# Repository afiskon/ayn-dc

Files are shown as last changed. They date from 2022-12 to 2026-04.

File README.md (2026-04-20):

# AYN/DC

QRP CW Transceiver

* Covers 40, 30, 20 and 17 meters
* Easily modifiable for other 4 bands
* DC receiver with sideband suppression
* Simple but effective AGC
* Supports RIT and XIT
* 10-30 WPM Elekey-B type keyer + straight key mode
* Keyer settings are saved in EEPROM
* ~5W class C power amplifier
* Has a VCC indicator and a SWR meter
* PCB is designed to fit into Hammond 1590BB enclosure
* The project is 100% open-source

Links:

* Article (in Russian): https://eax.me/2023/2023-01-16-ayn-dc-transceiver.html
* Demo: https://www.youtube.com/watch?v=9x_RN68QJhk

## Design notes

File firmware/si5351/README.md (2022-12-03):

# stm32-si5351

HAL-based Si5351 driver for STM32.

Main respository: https://github.com/afiskon/stm32-si5351

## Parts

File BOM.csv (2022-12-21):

Reference | Quantity | Value | Footprint
C13 C18 C21 C58 C59 | 5 | 0.01u | Capacitor_SMD:C_0805_2012Metric_Pad1.15x1.40mm_HandSolder
C2 | 1 | 470u | Connector_PinSocket_2.54mm:PinSocket_1x02_P2.54mm_Vertical
C23 C31 C46 | 3 | 0.047u | Capacitor_SMD:C_0805_2012Metric_Pad1.15x1.40mm_HandSolder
C26 C27 C36 | 3 | 1000p | Capacitor_SMD:C_0805_2012Metric_Pad1.15x1.40mm_HandSolder
C29 C66 C69 | 3 | 100p | Capacitor_SMD:C_0805_2012Metric_Pad1.15x1.40mm_HandSolder
C3 C6 C24 | 3 | 0.47u | Capacitor_SMD:C_0805_2012Metric_Pad1.15x1.40mm_HandSolder
C32 C40 | 2 | 0.033u | Capacitor_SMD:C_0805_2012Metric_Pad1.15x1.40mm_HandSolder
C33 C38 C39 | 3 | 2200p | Capacitor_SMD:C_0805_2012Metric_Pad1.15x1.40mm_HandSolder
C34 | 1 | 4.7u | Capacitor_SMD:CP_Elec_4x5.4
C35 C47 | 2 | 10u | Capacitor_SMD:CP_Elec_4x5.4
C1 C4 C5 C7 C8 C9 C10 C11 C12 C14 C15 C16 C17 C19 C20 C22 C25 C28 C30 C37 C42 C43 C44 C49 C50 C51 C53 C54 C55 C56 C57 | 31 | 0.1u | Capacitor_SMD:C_0805_2012Metric_Pad1.15x1.40mm_HandSolder
C41 | 1 | 6800p | Capacitor_SMD:C_0805_2012Metric_Pad1.15x1.40mm_HandSolder
C48 | 1 | 1u | Capacitor_SMD:CP_Elec_4x5.4
C52 | 1 | 220u | Capacitor_SMD:CP_Elec_8x10.5
C60 | 1 | 1-20p | My_Library:C_Trim_THD_L7.0mm_W6.5mm_P5.00mm
C61 C64 | 2 | 150p | Capacitor_SMD:C_0805_2012Metric_Pad1.15x1.40mm_HandSolder
C62 C63 C67 C68 C72 C73 C77 C78 | 8 | 1-30p | My_Library:C_Trim_THD_L7.0mm_W6.5mm_P5.00mm
C65 C70 C75 | 3 | 1-10p | My_Library:C_Trim_THD_L7.0mm_W6.5mm_P5.00mm
C71 C74 | 2 | 47p | Capacitor_SMD:C_0805_2012Metric_Pad1.15x1.40mm_HandSolder
C76 C79 | 2 | 68p | Capacitor_SMD:C_0805_2012Metric_Pad1.15x1.40mm_HandSolder
D1 D2 D3 D6 D7 D8 D9 D10 D11 D12 D13 | 11 | 1N4148W | Diode_SMD:D_SOD-123
D14 | 1 | SS14 | Diode_SMD:D_SMA_Handsoldering
D4 D5 | 2 | 1N34 / D311 / etc | Diode_THT:D_DO-41_SOD81_P3.81mm_Vertical_AnodeUp
J2 | 1 | Si5351 Module | Connector_PinSocket_2.54mm:PinSocket_1x07_P2.54mm_Vertical
J3, J4 | 1 | Blue Pill
K1 K2 K3 K4 K5 K6 K7 K8 K9 | 9 | G6K-2F-Y or HFD4/12-S | Relay_SMD:Relay_DPDT_Omron_G6K-2F-Y
L1 L2 | 2 | 1000u | Inductor_THT:L_Axial_L6.6mm_D2.7mm_P10.16mm_Horizontal_Vishay_IM-2
Q1 Q5 Q7 Q8 Q9 Q10 Q11 | 7 | MMBT3904 | Package_TO_SOT_SMD:SOT-23
Q2 Q3 | 2 | MMBF170 | Package_TO_SOT_SMD:SOT-23
Q4 | 1 | MMBT3906 | Package_TO_SOT_SMD:SOT-23
Q6 | 1 | RD15HVF1 | Package_TO_SOT_THT:TO-220-3_Vertical
R1 R41 | 2 | 15K | Resistor_SMD:R_0805_2012Metric_Pad1.15x1.40mm_HandSolder
R7 R8 R10 R13 | 4 | 300 | Resistor_SMD:R_0805_2012Metric_Pad1.15x1.40mm_HandSolder
R19 R40 | 2 | 8.2K | Resistor_SMD:R_0805_2012Metric_Pad1.15x1.40mm_HandSolder
R2 R15 R16 R54 R66 R67 R68 R69 | 8 | 4.7K | Resistor_SMD:R_0805_2012Metric_Pad1.15x1.40mm_HandSolder
R20 R28 R53 R59 R71 R72 | 6 | 1K | Resistor_SMD:R_0805_2012Metric_Pad1.15x1.40mm_HandSolder
R21 R22 R23 R24 R29 R30 R31 R32 R57 | 9 | 3.3K | Resistor_SMD:R_0805_2012Metric_Pad1.15x1.40mm_HandSolder
R26 | 1 | 5.1K | Resistor_SMD:R_0805_2012Metric_Pad1.15x1.40mm_HandSolder
R27 | 1 | 4.3K | Resistor_SMD:R_0805_2012Metric_Pad1.15x1.40mm_HandSolder
R3 | 1 | 2.7K | Resistor_SMD:R_0805_2012Metric_Pad1.15x1.40mm_HandSolder
R35 R36 | 2 | 33K | Resistor_SMD:R_0805_2012Metric_Pad1.15x1.40mm_HandSolder
R37 R38 | 2 | 47K | Resistor_SMD:R_0805_2012Metric_Pad1.15x1.40mm_HandSolder
R45 | 1 | 750K | Resistor_SMD:R_0805_2012Metric_Pad1.15x1.40mm_HandSolder
R46 R47 | 2 | 36K | Resistor_SMD:R_0805_2012Metric_Pad1.15x1.40mm_HandSolder
R50 | 1 | 10 | Resistor_SMD:R_0805_2012Metric_Pad1.15x1.40mm_HandSolder
R51 | 1 | 1Meg | Resistor_SMD:R_0805_2012Metric_Pad1.15x1.40mm_HandSolder
R52 | 1 | 470 | Resistor_SMD:R_0805_2012Metric_Pad1.15x1.40mm_HandSolder
R56 | 1 | 2.2K | Resistor_SMD:R_0805_2012Metric_Pad1.15x1.40mm_HandSolder
R58 | 1 | 1.3K | Resistor_SMD:R_0805_2012Metric_Pad1.15x1.40mm_HandSolder
R6 R17 R25 R33 R43 R49 R55 | 7 | 22 | Resistor_SMD:R_0805_2012Metric_Pad1.15x1.40mm_HandSolder
R60 | 1 | 68 | Resistor_SMD:R_0805_2012Metric_Pad1.15x1.40mm_HandSolder
R61 | 1 | 6 | Resistor_SMD:R_0805_2012Metric_Pad1.15x1.40mm_HandSolder
R62 R63 R64 R65 | 4 | 100 | Resistor_SMD:R_0805_2012Metric_Pad1.15x1.40mm_HandSolder
R70 | 1 | 100K | Resistor_SMD:R_0805_2012Metric_Pad1.15x1.40mm_HandSolder
R9 R11 R12 R14 R18 R34 R39 R42 R44 R48 | 10 | 10K | Resistor_SMD:R_0805_2012Metric_Pad1.15x1.40mm_HandSolder
RV1 RV2 | 2 | 50K | Potentiometer_THT:Potentiometer_Bourns_3296W_Vertical
RV3 | 1 | 500 | Potentiometer_THT:Potentiometer_Bourns_3296W_Vertical
RV4 RV5 | 2 | 10K | Potentiometer_THT:Potentiometer_Bourns_3296W_Vertical
T1 T2 T3 | 3 | FT37-43 | Package_DIP:DIP-4_W7.62mm
T4 T5 T6 T7 T8 T9 T10 T11 | 8 | T37-6 | Package_DIP:DIP-4_W7.62mm
U1 | 1 | L7805 | Package_TO_SOT_THT:TO-220-3_Vertical
U10 | 1 | LM386 | Package_SO:SO-8_5.3x6.2mm_P1.27mm
U11 | 1 | L7805 | Package_TO_SOT_SMD:TO-263-2
U2 | 1 | 24LC64 | Package_SO:SO-8_5.3x6.2mm_P1.27mm
U3 U6 U7 U8 U9 | 5 | NE5532 | Package_SO:SOIC-8_5.23x5.23mm_P1.27mm
U4 | 1 | FST3253 | Package_SO:TSSOP-16_4.4x5mm_P0.65mm
U5 | 1 | 74AC74 | Package_SO:SOIC-14_3.9x8.7mm_P1.27mm
J8 J9 J11 J12 | 1 | BN61-202
J6 | 2 | 220u | Through-hole capacitors, ideally 8 mm diameter

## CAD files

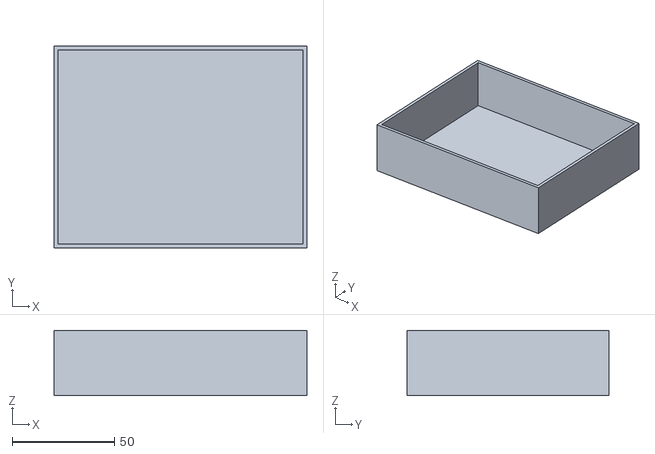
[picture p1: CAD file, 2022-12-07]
stl-files/dust-cover.stl
124.0 x 99.0 x 32.0

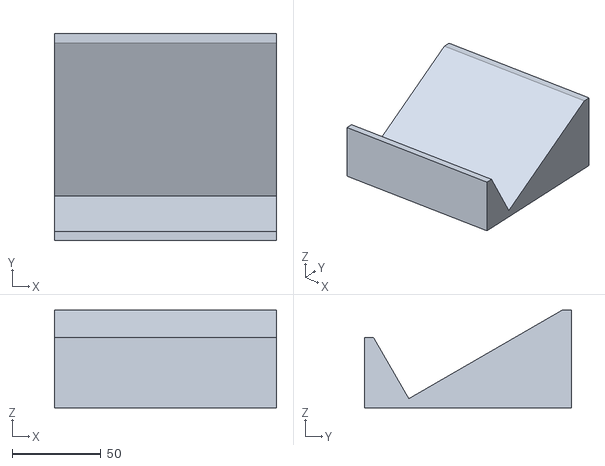
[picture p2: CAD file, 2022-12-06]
stl-files/desktop-stand.stl
125.0 x 116.6 x 55.0

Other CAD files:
stl-files/desktop-stand.scad
stl-files/dust-cover.scad

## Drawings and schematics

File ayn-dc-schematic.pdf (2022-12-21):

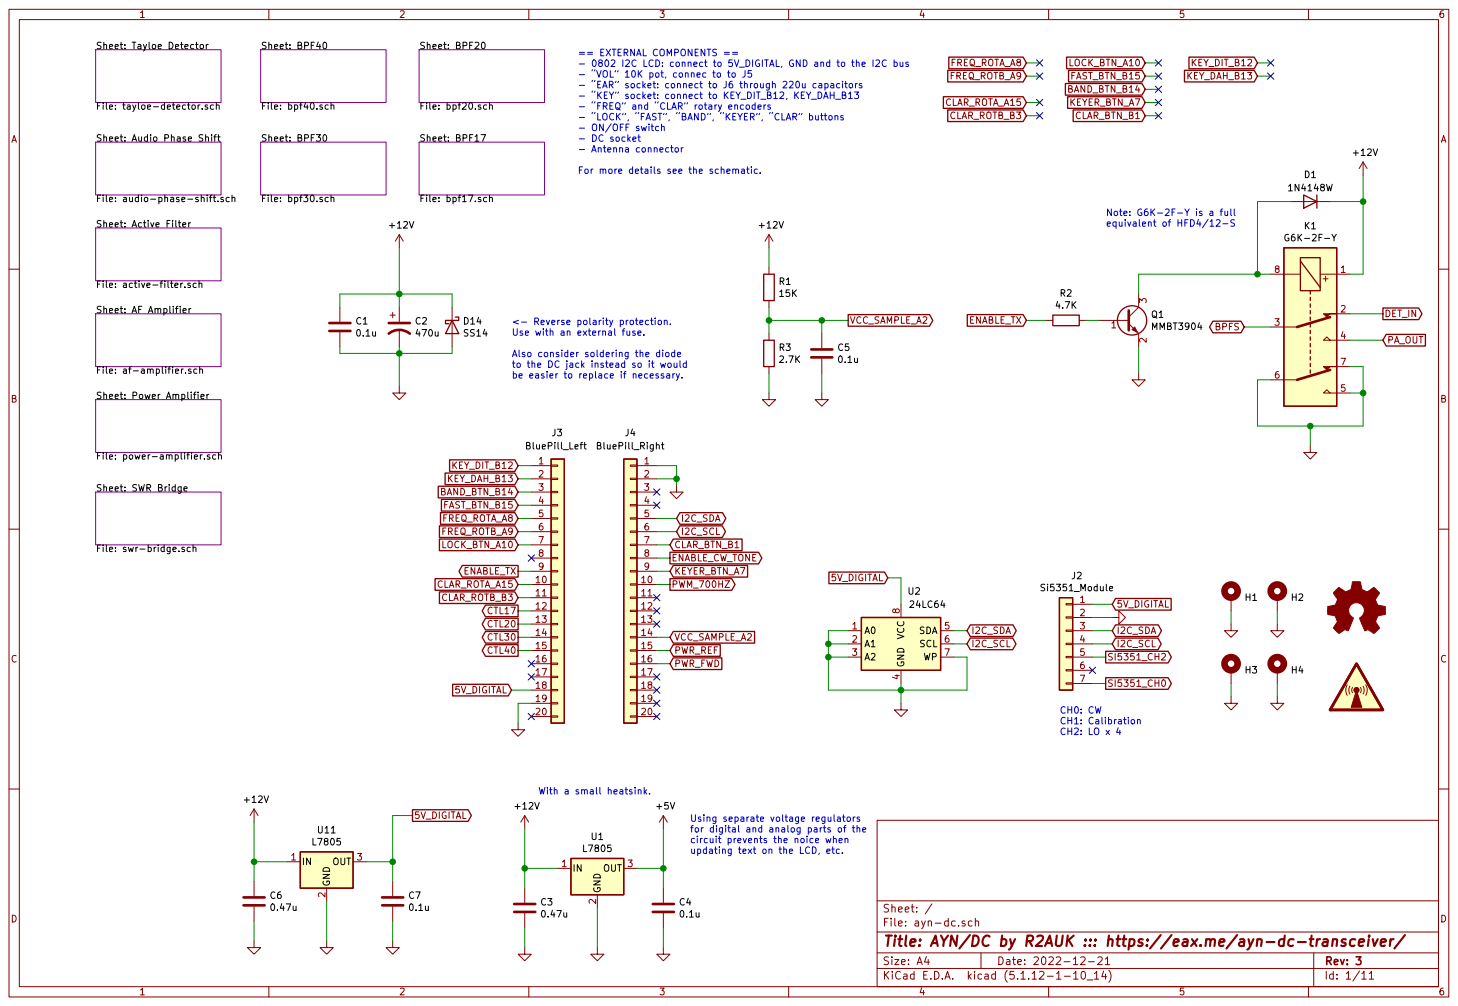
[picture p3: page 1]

== EXTERNAL COMPONENTS ==
- 0802 I2C LCD: connect to 5V_DIGITAL, GND and to the I2C bus
- VOL 10K pot, connec to to J5
- EAR socket: connect to J6 through 220u capacitors
- KEY socket: connect to KEY_DIT_B12, KEY_DAH_B13
- FREQ and CLAR rotary encoders
- LOCK, FAST, BAND, KEYER, CLAR buttons
- ON/OFF switch

File: tayloe-detector.sch Sheet: Audio Phase Shift File: audio-phase-shift.sch

<- Reverse polarity protection. Use with an external fuse. Also consider soldering the diode

to the DC jack instead so it would
be easier to replace if necessary.

File: power-amplifier.sch

File: swr-bridge.sch

4 SDA 5 SCL 6 WP 7 VCC

CH1: Calibration CH2: LO x 4 Using separate voltage regulators

for digital and analog parts of the
circuit prevents the noice when
updating text on the LCD, etc.

File: ayn-dc.sch Sheet: /
Id: 1/11 Title: AYN/DC by R2AUK ::: https://eax.me/ayn-dc-transceiver/

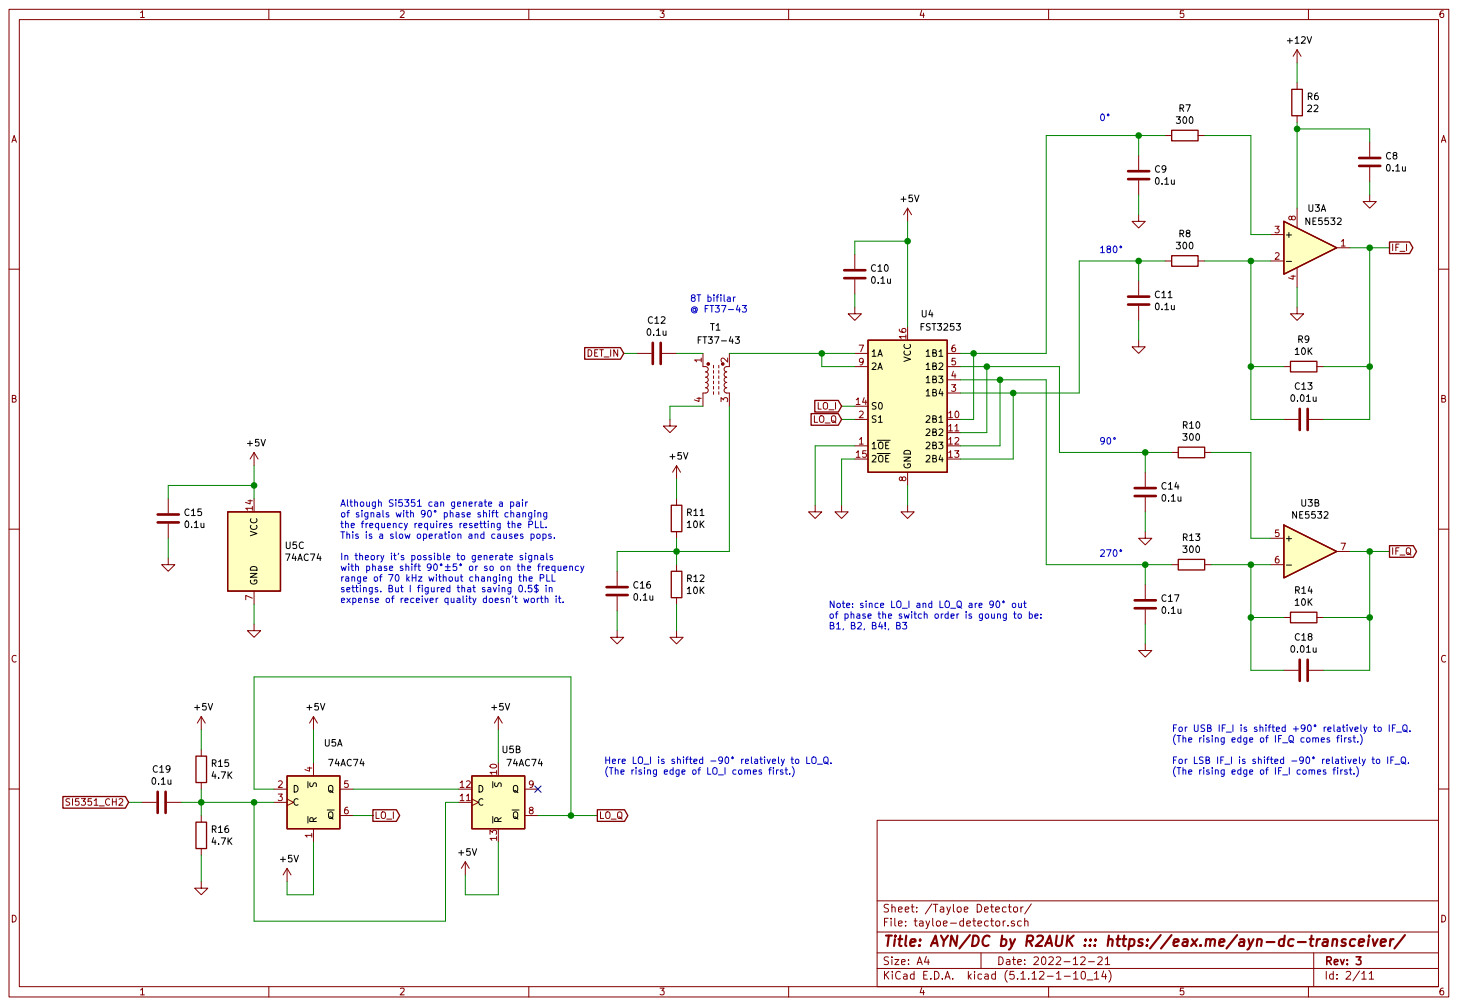
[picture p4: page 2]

0° 180° Note: since LO_I and LO_Q are 90° out of phase the switch order is goung to be: B1, B2, B4!, B3

Although Si5351 can generate a pair
of signals with 90° phase shift changing
the frequency requires resetting the PLL.
This is a slow operation and causes pops.

In theory its possible to generate signals
with phase shift 90°±5° or so on the frequency
range of 70 kHz without changing the PLL
settings. But I figured that saving 0.5$ in

For USB IF_I is shifted +90° relatively to IF_Q.
(The rising edge of IF_Q comes first.)

Here LO_I is shifted -90° relatively to LO_Q.
(The rising edge of LO_I comes first.)

For LSB IF_I is shifted -90° relatively to IF_Q.
(The rising edge of IF_I comes first.)

File: tayloe-detector.sch
Id: 2/11 Title: AYN/DC by R2AUK ::: https://eax.me/ayn-dc-transceiver/

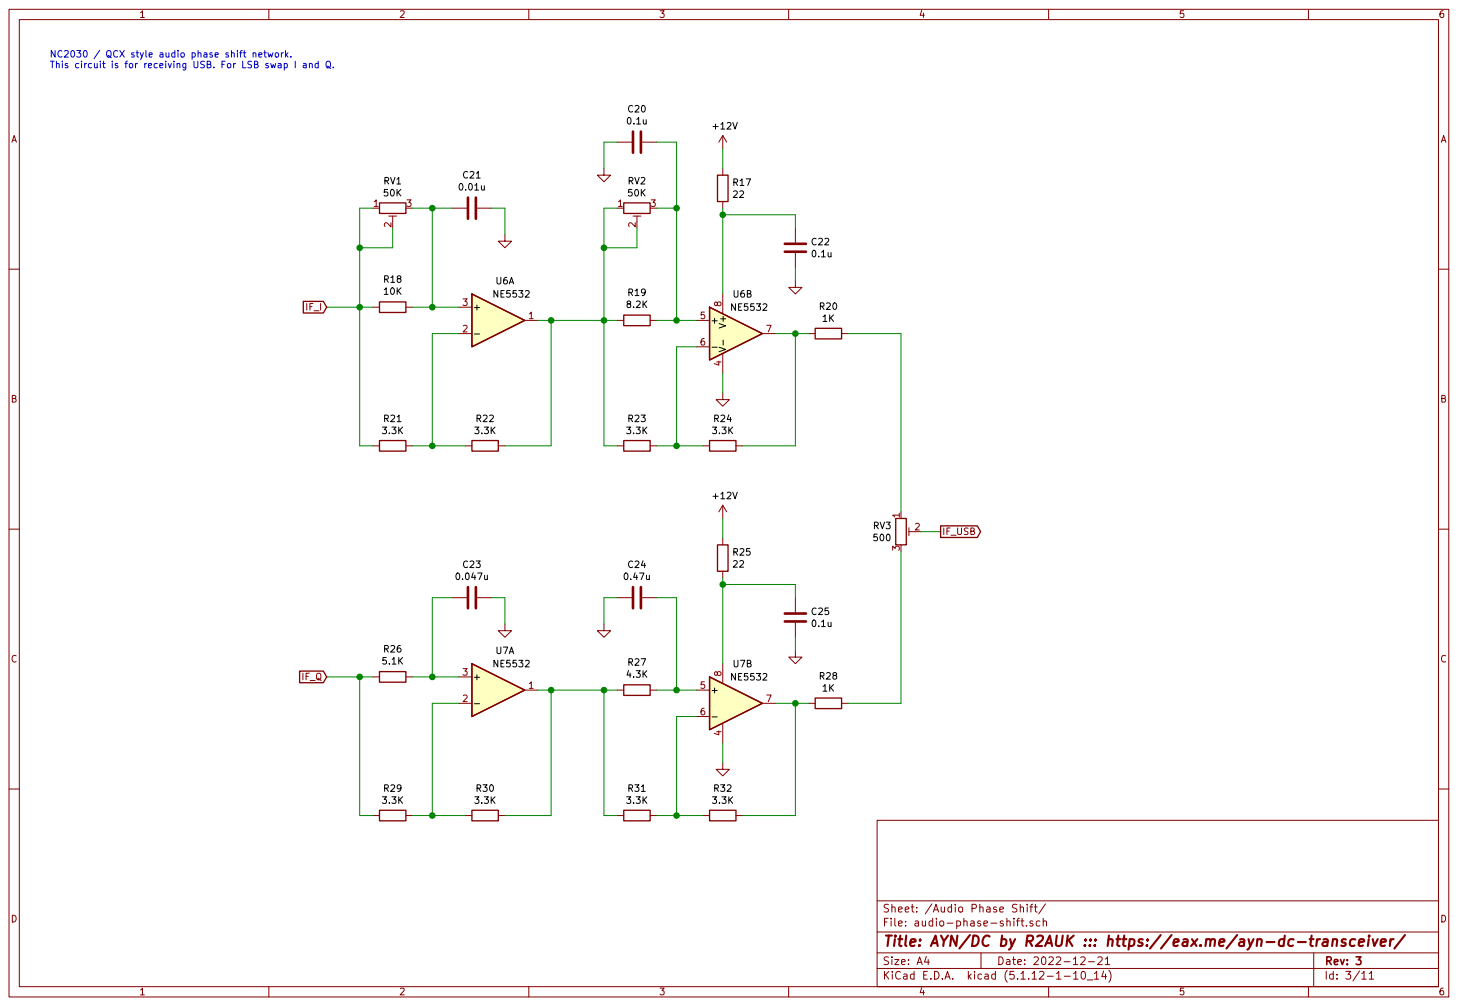
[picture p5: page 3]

NC2030 / QCX style audio phase shift network.
This circuit is for receiving USB. For LSB swap I and Q.

File: audio-phase-shift.sch Sheet: /Audio Phase Shift/
Id: 3/11 Title: AYN/DC by R2AUK ::: https://eax.me/ayn-dc-transceiver/

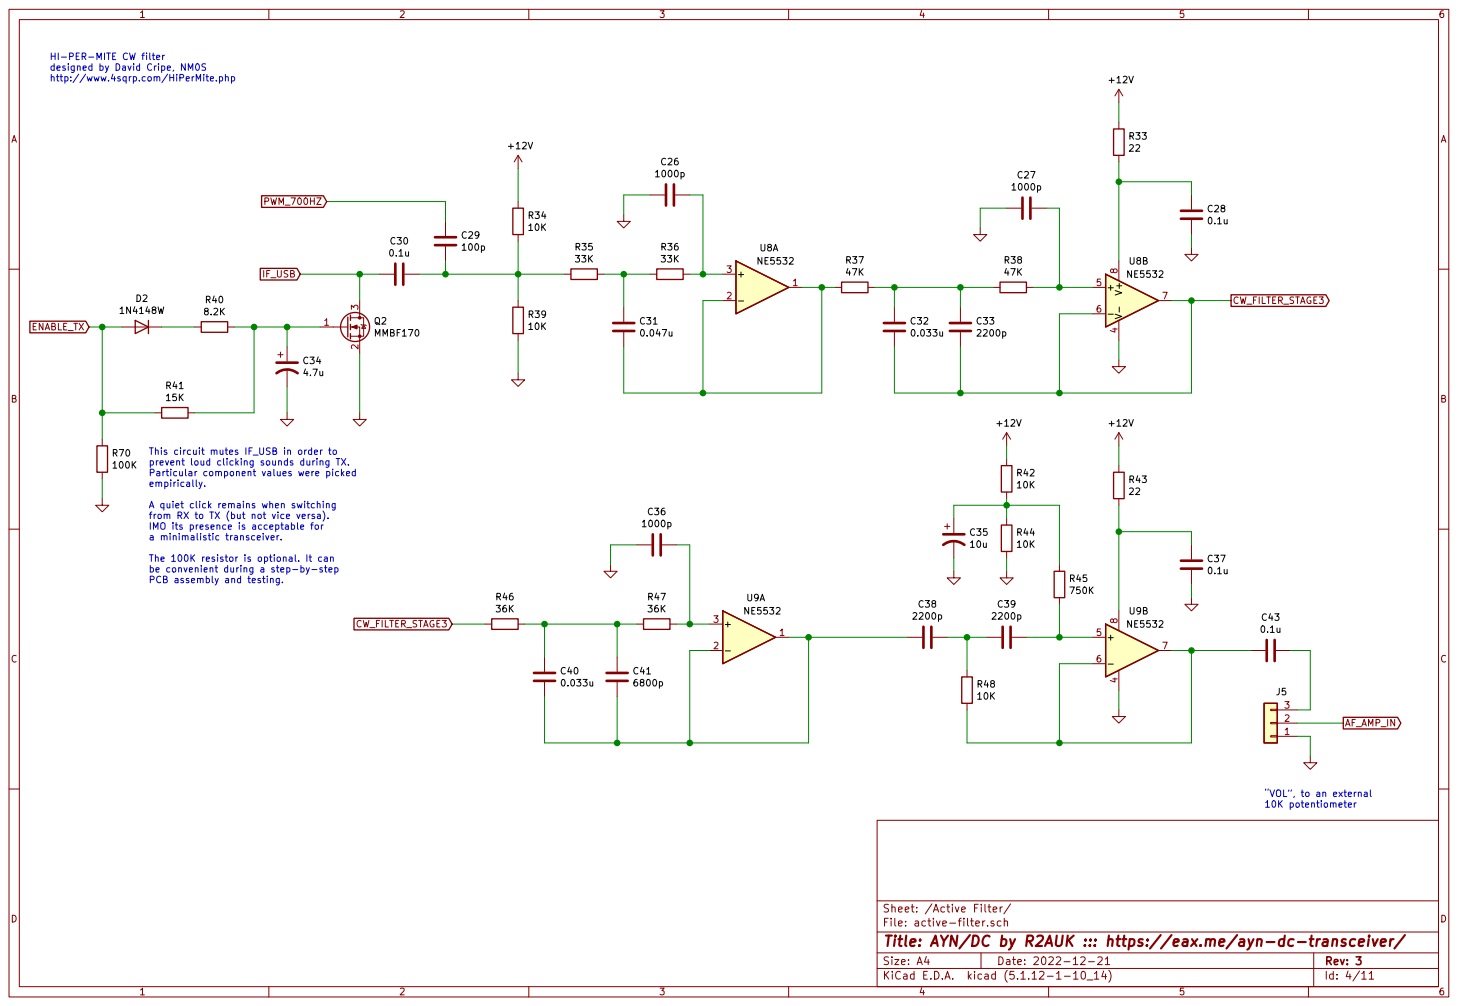
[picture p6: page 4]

HI-PER-MITE CW filter designed by David Cripe, NM0S

http://www.4sqrp.com/HiPerMite.php

This circuit mutes IF_USB in order to
prevent loud clicking sounds during TX.
Particular component values were picked
empirically.

A quiet click remains when switching
from RX to TX (but not vice versa).
IMO its presence is acceptable for a minimalistic transceiver. The 100K resistor is optional. It can

be convenient during a step-by-step
PCB assembly and testing.

VOL, to an external 10K potentiometer

Id: 4/11 Title: AYN/DC by R2AUK ::: https://eax.me/ayn-dc-transceiver/ File: active-filter.sch Sheet: /Active Filter/

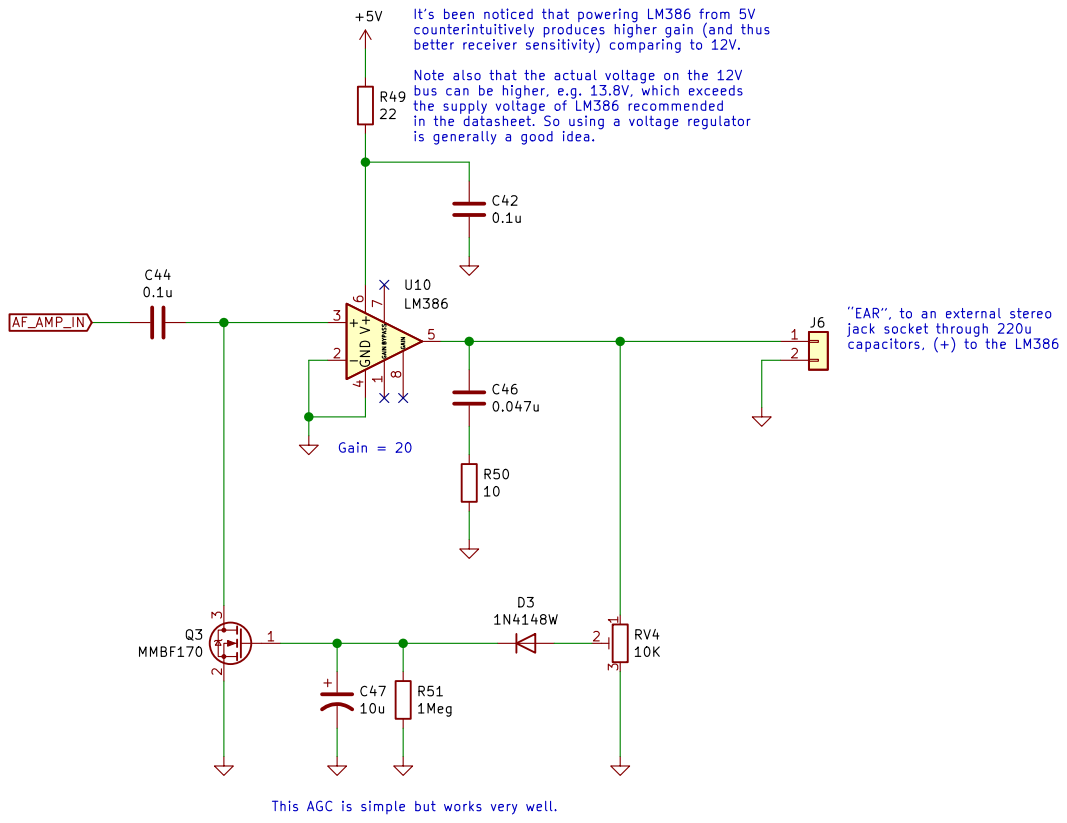
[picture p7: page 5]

is generally a good idea. Gain = 20 This AGC is simple but works very well.

Its been noticed that powering LM386 from 5V
counterintuitively produces higher gain (and thus
better receiver sensitivity) comparing to 12V.
the supply voltage of LM386 recommended
in the datasheet. So using a voltage regulator

Note also that the actual voltage on the 12V
bus can be higher, e.g. 13.8V, which exceeds

Sheet: /AF Amplifier/
File: af-amplifier.sch
Id: 5/11 Title: AYN/DC by R2AUK ::: https://eax.me/ayn-dc-transceiver/

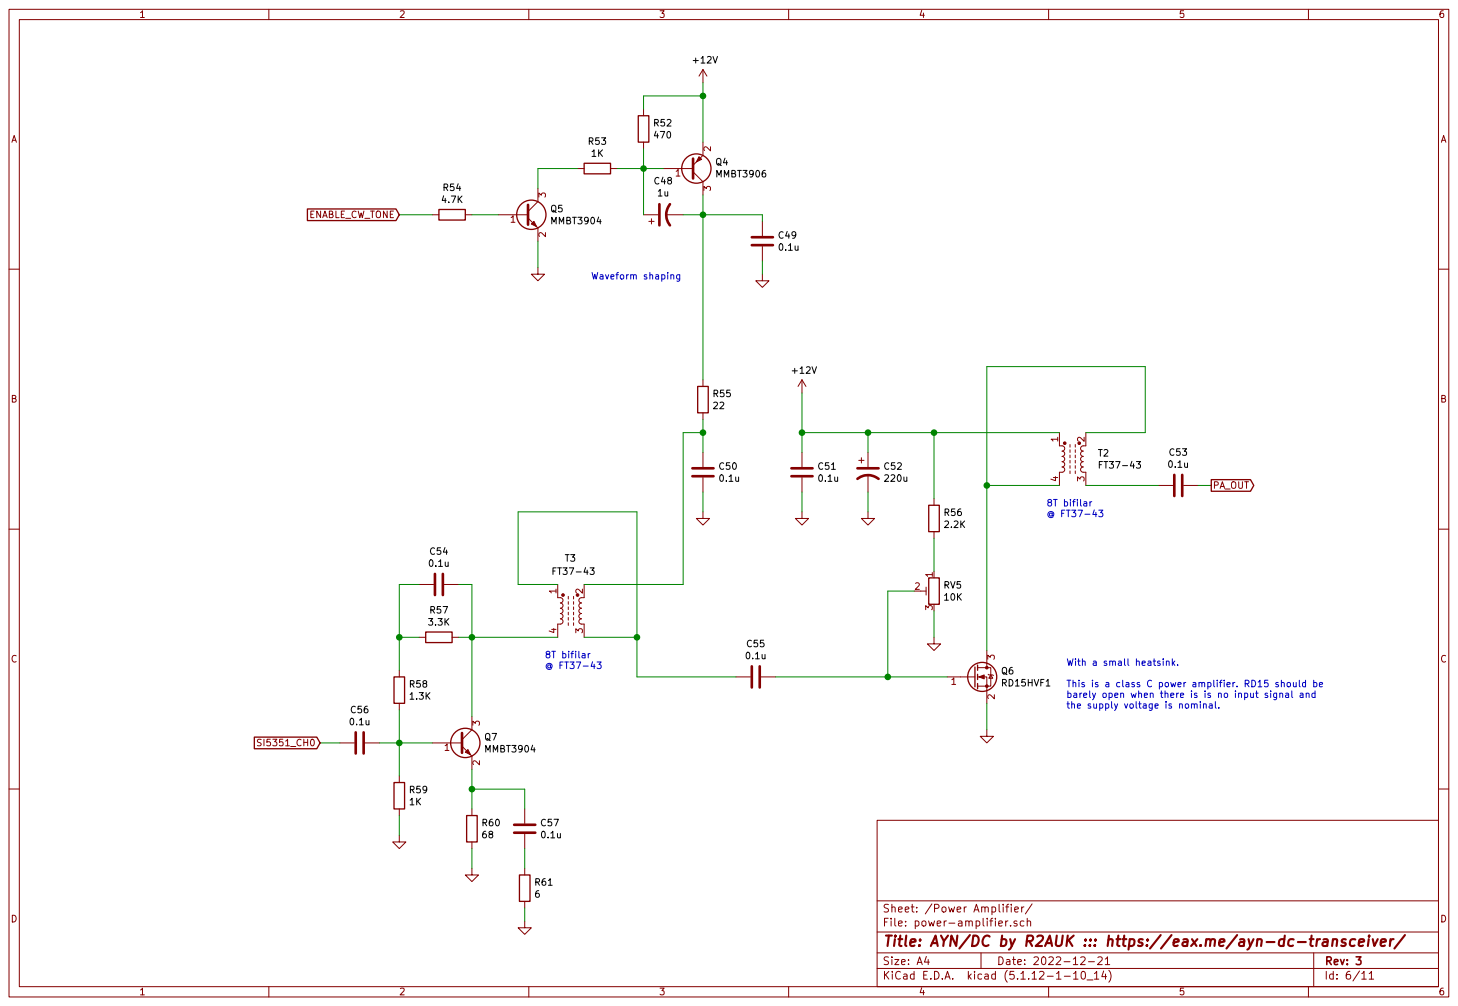
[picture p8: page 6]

PA_OUT With a small heatsink. This is a class C power amplifier. RD15 should be
the supply voltage is nominal. 8T bifilar @ FT37-43

barely open when there is is no input signal and

File: power-amplifier.sch
Id: 6/11 Title: AYN/DC by R2AUK ::: https://eax.me/ayn-dc-transceiver/

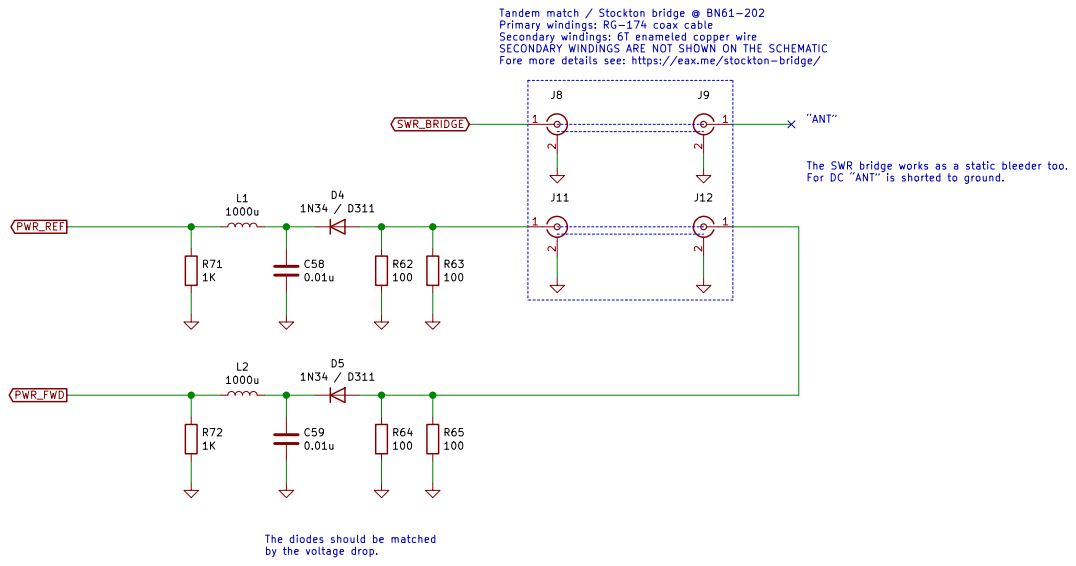
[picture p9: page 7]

Tandem match / Stockton bridge @ BN61-202
Primary windings: RG-174 coax cable
Secondary windings: 6T enameled copper wire SECONDARY WINDINGS ARE NOT SHOWN ON THE SCHEMATIC

Fore more details see: https://eax.me/stockton-bridge/ The diodes should be matched

The SWR bridge works as a static bleeder too.
For DC ANT is shorted to ground.

File: swr-bridge.sch
Id: 7/11 Title: AYN/DC by R2AUK ::: https://eax.me/ayn-dc-transceiver/

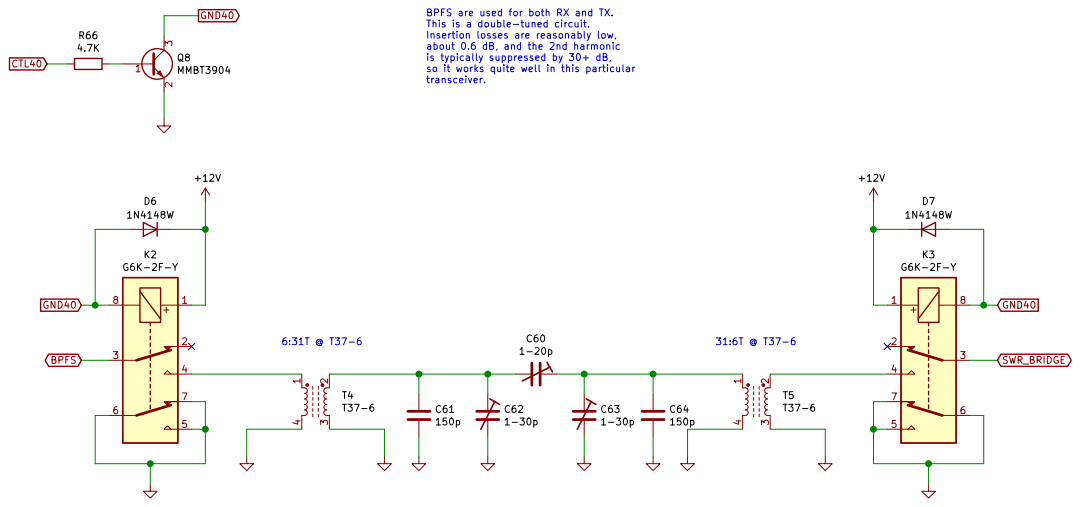
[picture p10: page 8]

Insertion losses are reasonably low, about 0.6 dB, and the 2nd harmonic

is typically suppressed by 30+ dB,
so it works quite well in this particular
transceiver.

Id: 8/11 Title: AYN/DC by R2AUK ::: https://eax.me/ayn-dc-transceiver/

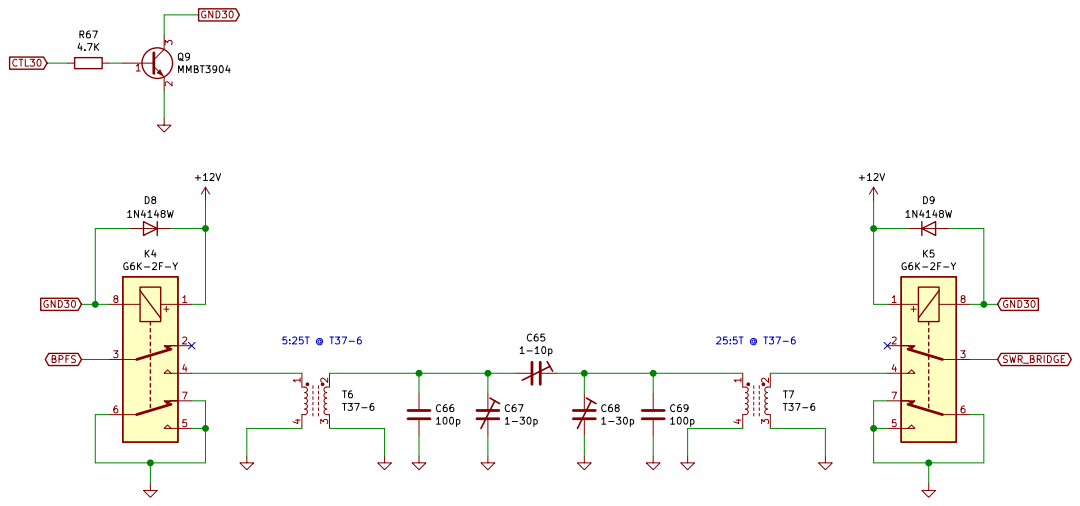
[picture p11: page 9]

File: bpf30.sch Sheet: /BPF30/
Id: 9/11 Title: AYN/DC by R2AUK ::: https://eax.me/ayn-dc-transceiver/

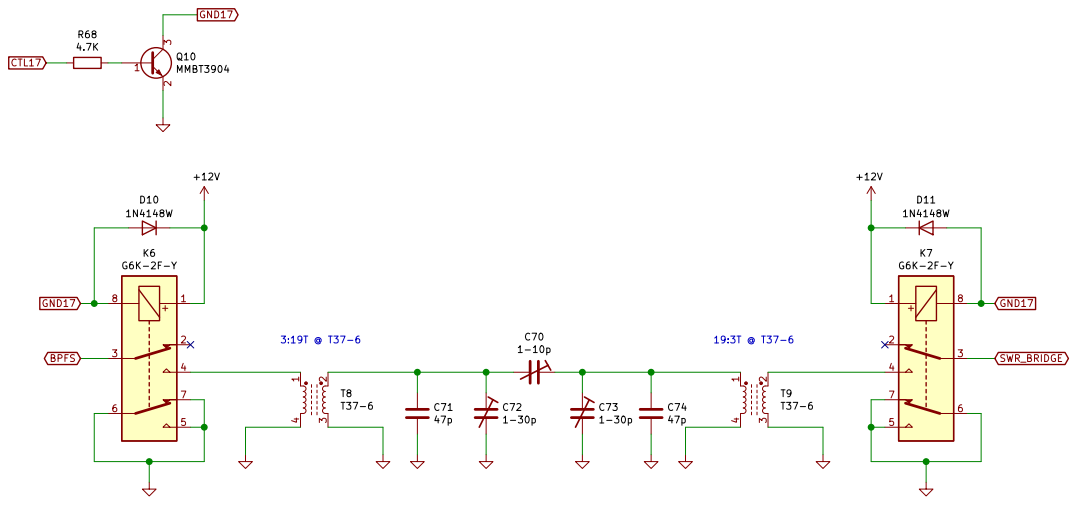
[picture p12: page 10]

File: bpf17.sch Sheet: /BPF17/
Id: 10/11 Title: AYN/DC by R2AUK ::: https://eax.me/ayn-dc-transceiver/

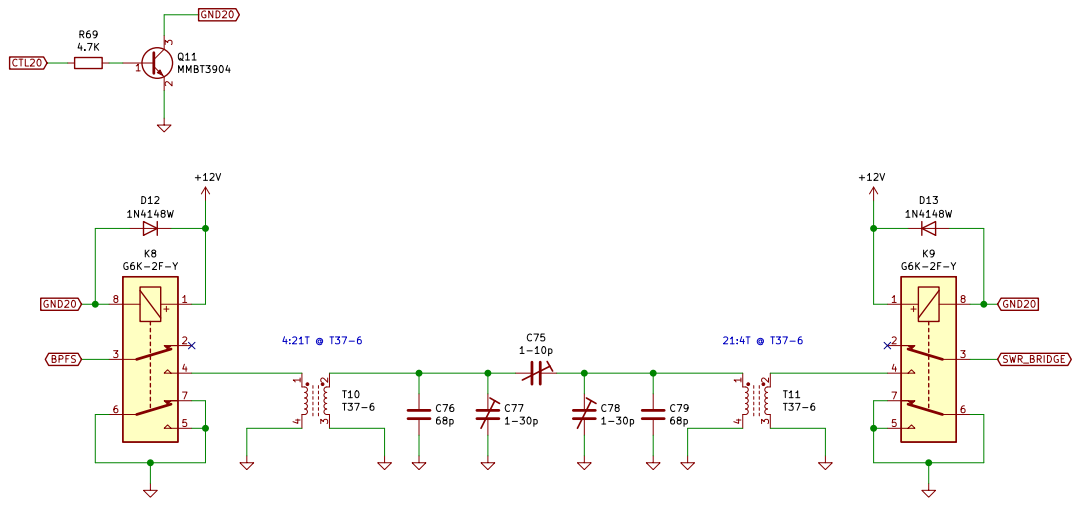
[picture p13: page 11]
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

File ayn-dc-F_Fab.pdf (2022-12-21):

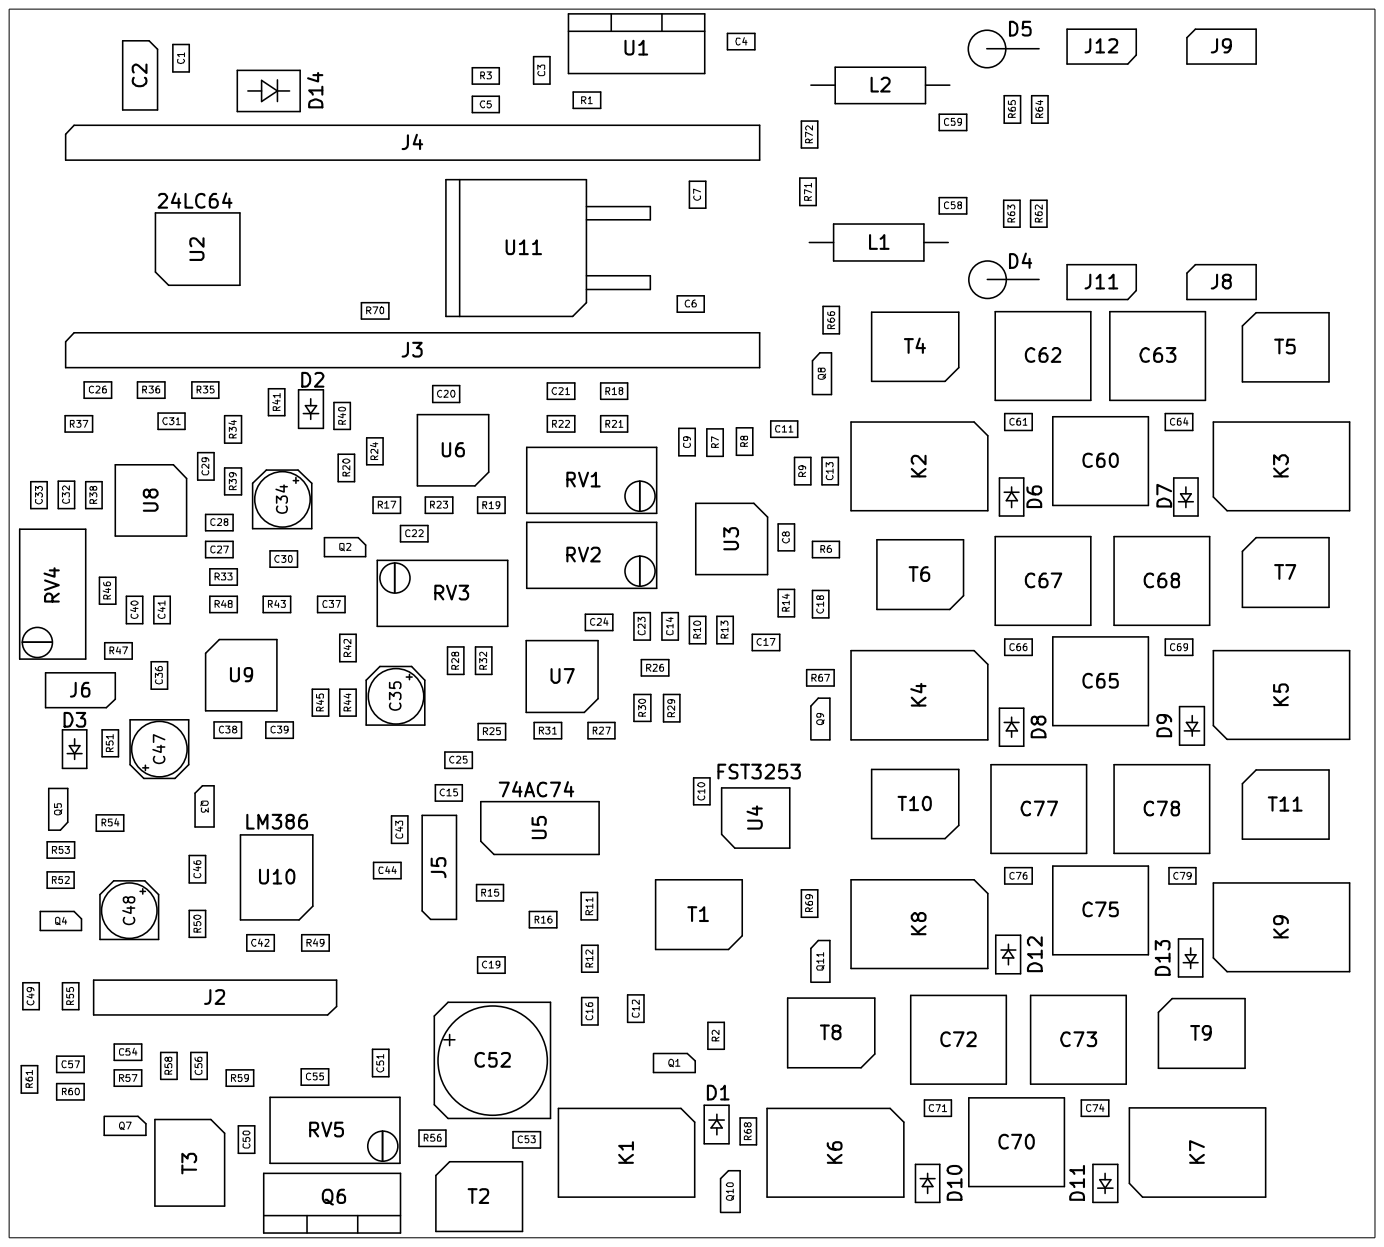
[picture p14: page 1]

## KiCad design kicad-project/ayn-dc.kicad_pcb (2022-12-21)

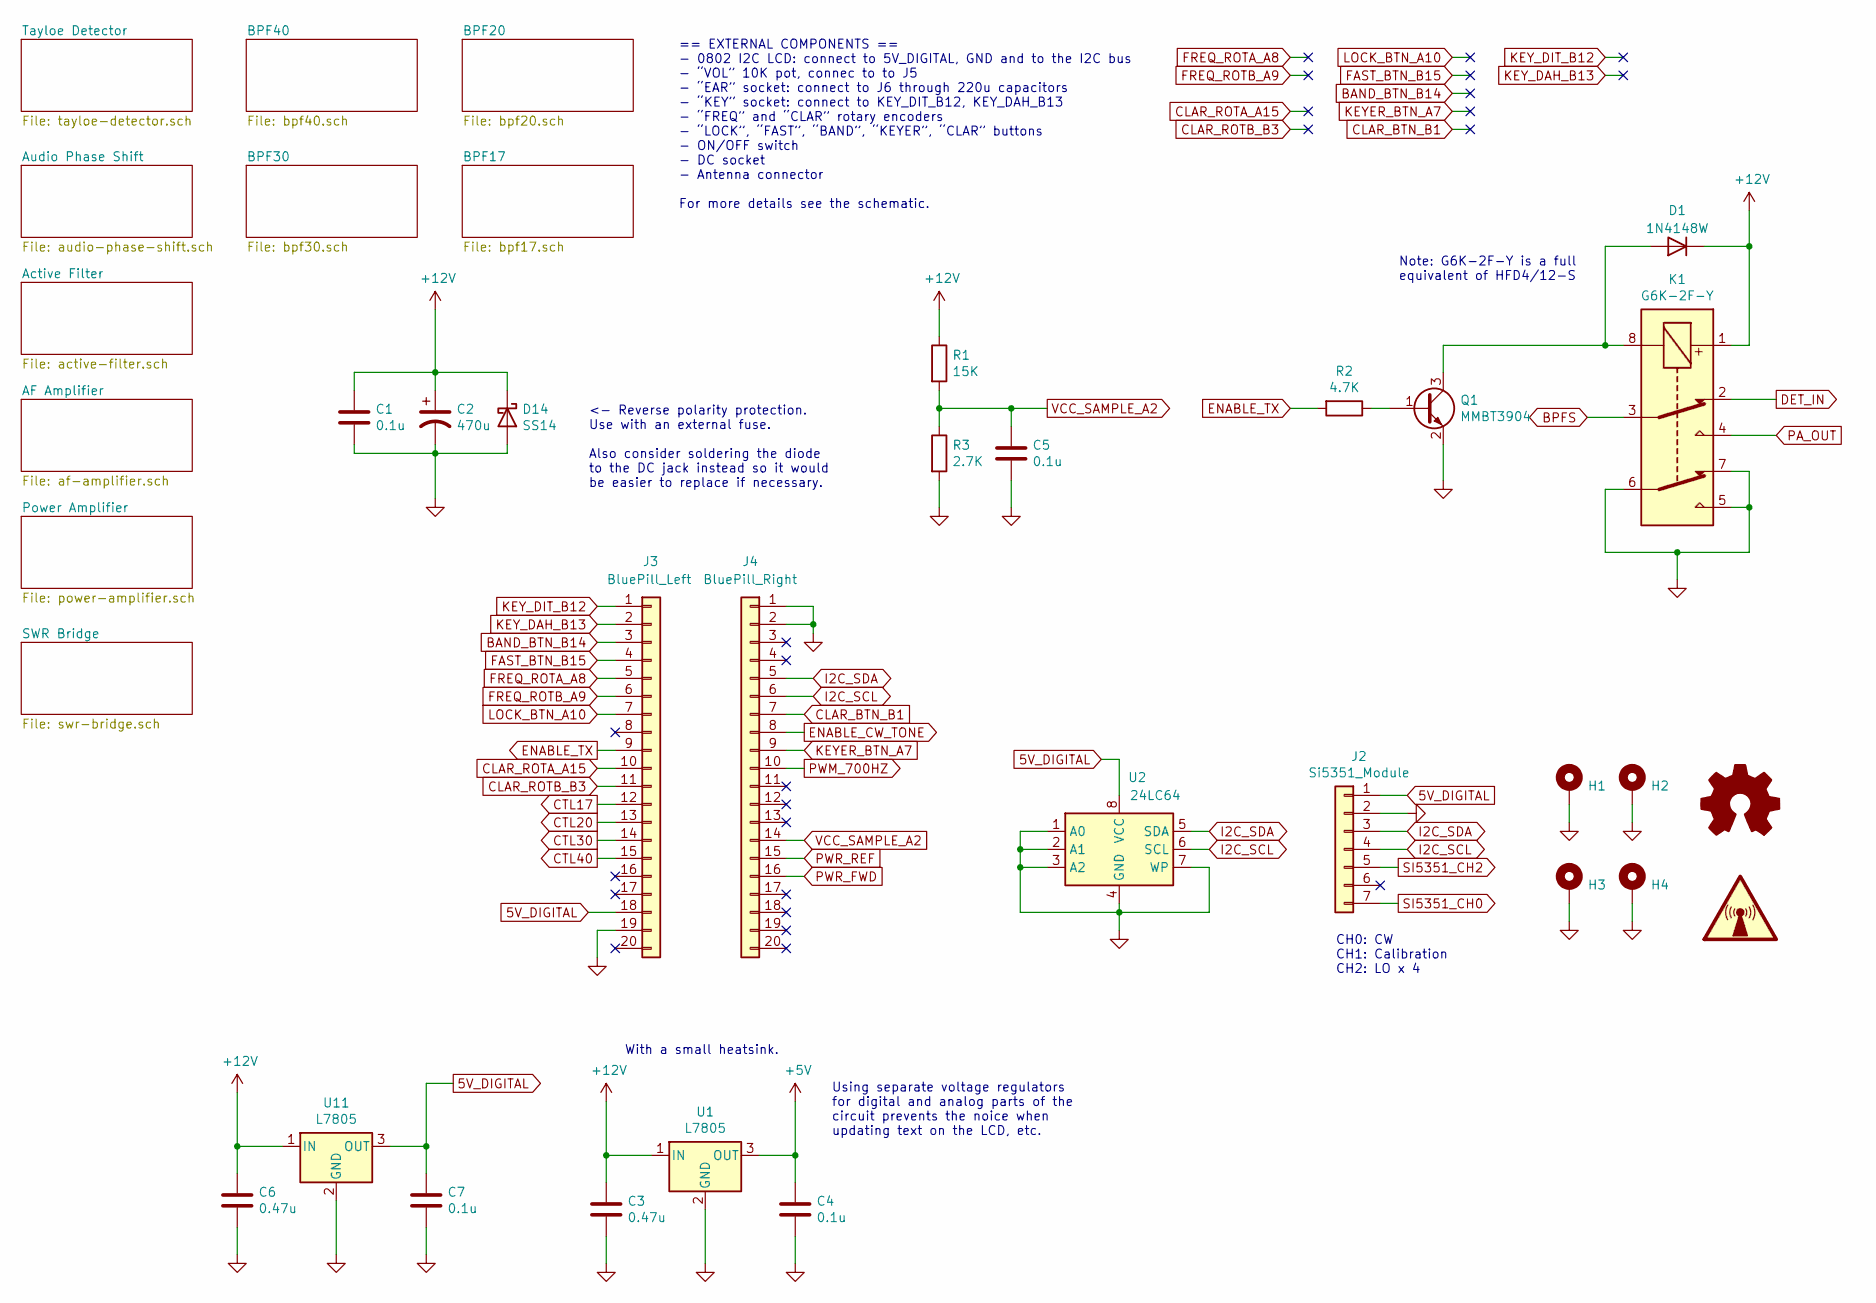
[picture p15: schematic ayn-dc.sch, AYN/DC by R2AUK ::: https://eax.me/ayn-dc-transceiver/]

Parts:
C1, C4, C5, C7: 0.1u; C_0805_2012Metric_Pad1.15x1.40mm_HandSolder
C2: 470u; PinSocket_1x02_P2.54mm_Vertical
C3, C6: 0.47u; C_0805_2012Metric_Pad1.15x1.40mm_HandSolder
D1: 1N4148W; D_SOD-123
D14: SS14; D_SMA_Handsoldering
H1, H2, H3, H4: MountingHole_Pad; MountingHole_3mm_Pad
J2: Si5351_Module; PinSocket_1x07_P2.54mm_Vertical
J3: BluePill_Left; PinSocket_1x20_P2.54mm_Vertical
J4: BluePill_Right; PinSocket_1x20_P2.54mm_Vertical
K1: G6K-2F-Y; Relay_DPDT_Omron_G6K-2F-Y
Q1: MMBT3904; SOT-23
R1: 15K; R_0805_2012Metric_Pad1.15x1.40mm_HandSolder
R2: 4.7K; R_0805_2012Metric_Pad1.15x1.40mm_HandSolder
R3: 2.7K; R_0805_2012Metric_Pad1.15x1.40mm_HandSolder
SYM1: Logo_Open_Hardware_Small; OSHW-Logo2_9.8x8mm_SilkScreen
SYM2: SYM_Radio_Waves_Large; KiCad-Logo_5mm_SilkScreen
U1: L7805; TO-220-3_Vertical
U2: 24LC64; SO-8_5.3x6.2mm_P1.27mm
U11: L7805; TO-263-2

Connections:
5V_DIGITAL: C7.1, J2.1, J3.18, U2.8 (VCC), U11.3 (OUT)
+5V: C4.1, U1.3 (OUT); also elsewhere on the board
+12V: C1.1, C2.1, C3.1, C6.1, D1.1 (K), D14.1 (K), K1.1, R1.1, U1.1 (IN), U11.1 (IN); also elsewhere on the board
BAND_BTN_B14: J3.3
BPFS: K1.3; also elsewhere on the board
CLAR_BTN_B1: J4.7
CLAR_ROTA_A15: J3.10
CLAR_ROTB_B3: J3.11
CTL17: J3.12; also elsewhere on the board
CTL20: J3.13; also elsewhere on the board
CTL30: J3.14; also elsewhere on the board
CTL40: J3.15; also elsewhere on the board
DET_IN: K1.2; also elsewhere on the board
ENABLE_CW_TONE: J4.8; also elsewhere on the board
ENABLE_TX: J3.9, R2.2; also elsewhere on the board
FAST_BTN_B15: J3.4
FREQ_ROTA_A8: J3.5
FREQ_ROTB_A9: J3.6
GND: C1.2, C2.2, C3.2, C4.2, C5.2, C6.2, C7.2, D14.2 (A), H1.1, H2.1, H3.1, H4.1, J2.2, J3.19, J4.1, J4.2, K1.5, K1.6, K1.7, Q1.2 (E), R3.2, U1.2 (GND), U2.1 (A0), U2.2 (A1), U2.3 (A2), U2.4 (GND), U2.7 (WP), U11.2 (GND); also elsewhere on the board
I2C_SCL: J2.4, J4.6, U2.6 (SCL)
I2C_SDA: J2.3, J4.5, U2.5 (SDA)
KEYER_BTN_A7: J4.9
KEY_DAH_B13: J3.2
KEY_DIT_B12: J3.1
LOCK_BTN_A10: J3.7
unnamed: D1.2 (A), K1.8, Q1.3 (C)
unnamed: Q1.1 (B), R2.1
PA_OUT: K1.4; also elsewhere on the board
PWM_700HZ: J4.10; also elsewhere on the board
PWR_FWD: J4.16; also elsewhere on the board
PWR_REF: J4.15; also elsewhere on the board
SI5351_CH0: J2.7; also elsewhere on the board
SI5351_CH2: J2.5; also elsewhere on the board
VCC_SAMPLE_A2: C5.1, J4.14, R1.2, R3.1

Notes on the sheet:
CH0: CW CH1: Calibration CH2: LO x 4
== EXTERNAL COMPONENTS == - 0802 I2C LCD: connect to 5V_DIGITAL, GND and to the I2C bus - “VOL” 10K pot, connec to to J5 - “EAR” socket: connect to J6 through 220u capacitors - “KEY” socket: connect to KEY_DIT_B12, KEY_DAH_B13 - “FREQ” and “CLAR” rotary encoders - “LOCK”, “FAST”, “BAND”, “KEYER”, “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
With a small heatsink.
Note: G6K-2F-Y is a full equivalent of HFD4/12-S
<- Reverse polarity protection. Use with an external fuse. Also consider soldering the diode to the DC jack instead so it would be easier to replace if necessary.
Using separate voltage regulators for digital and analog parts of the circuit prevents the noice when updating text on the LCD, etc.

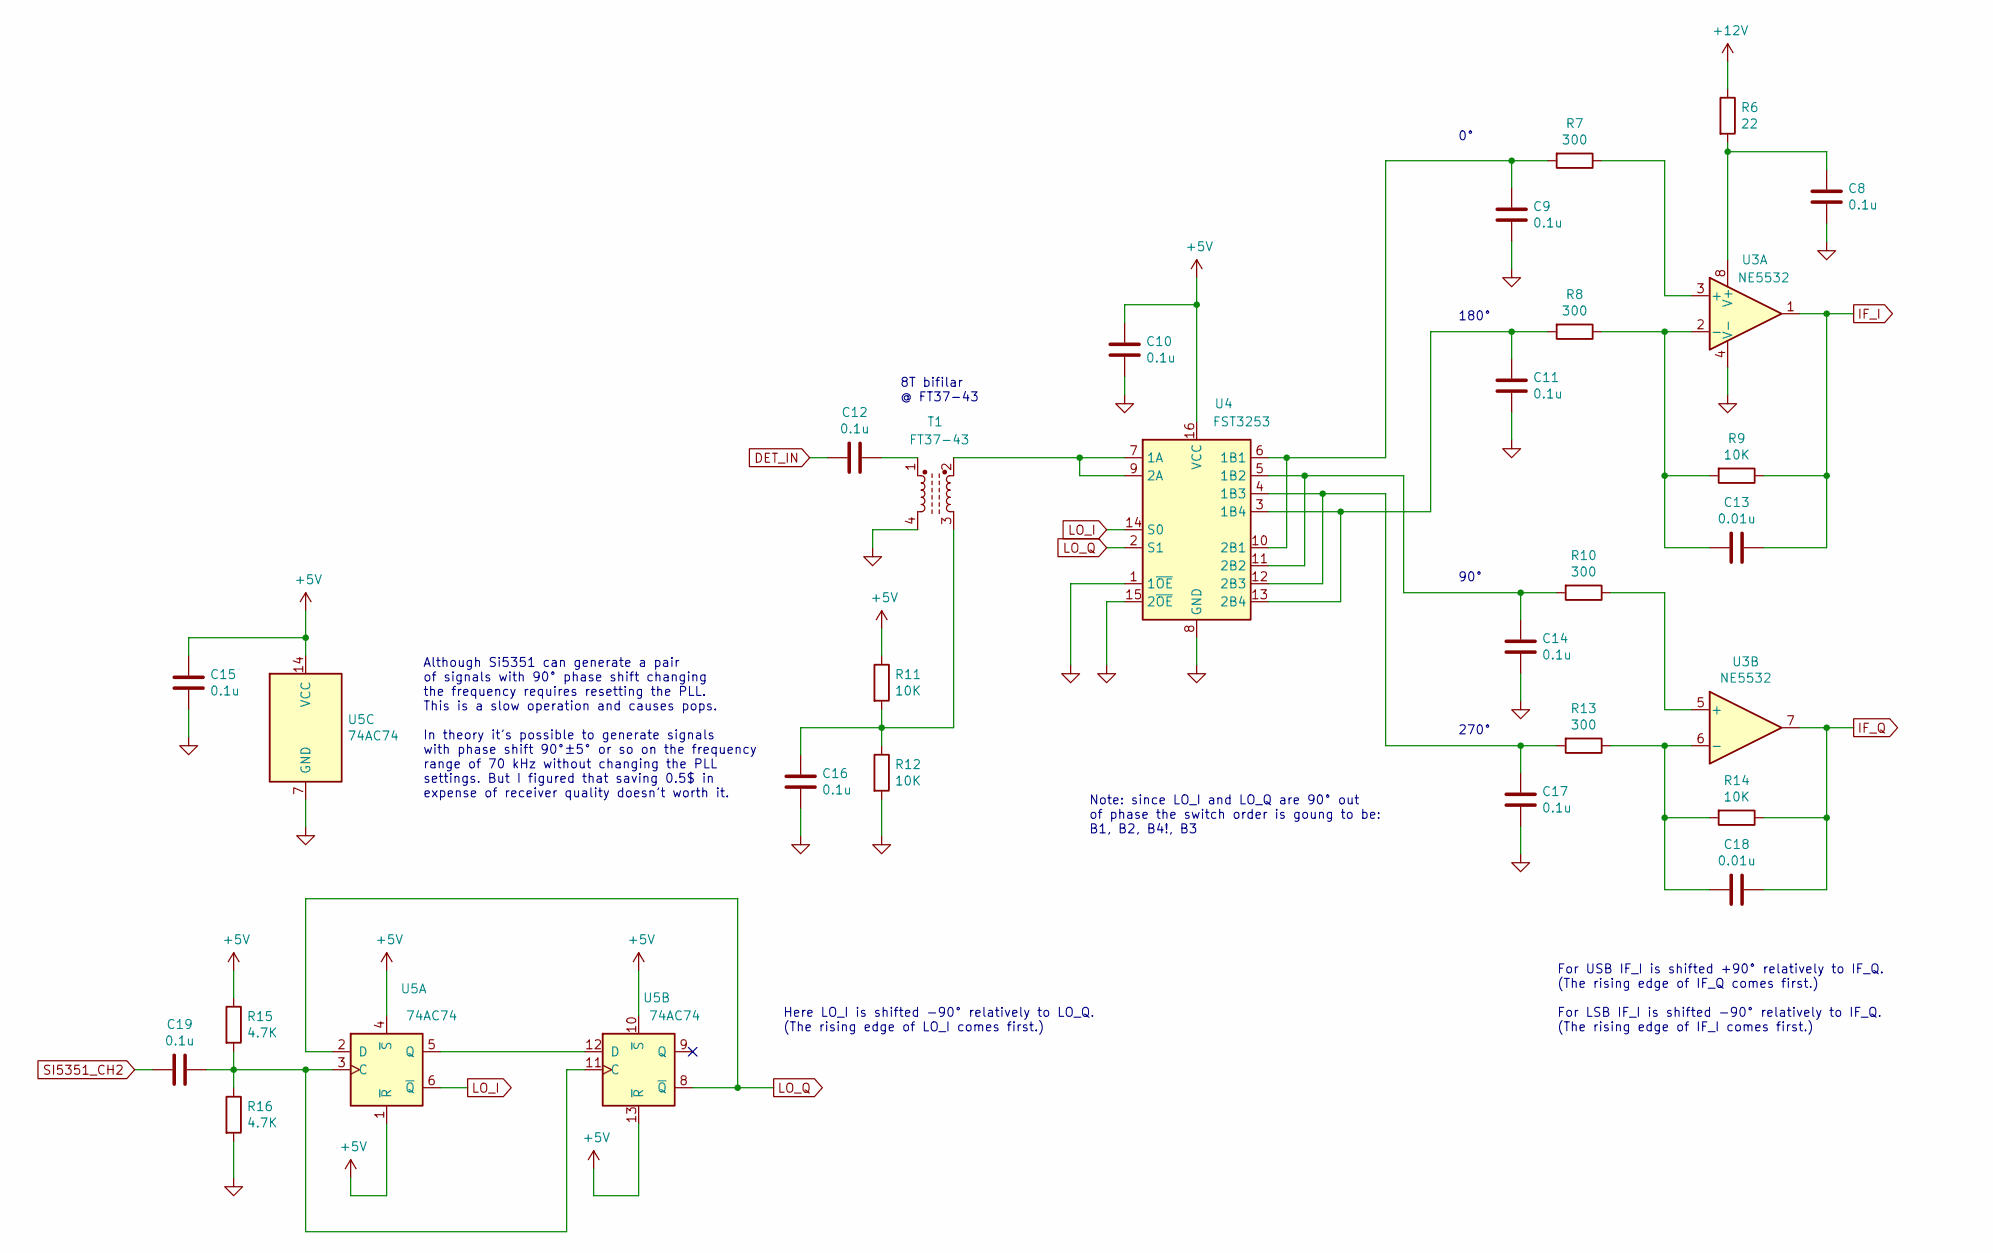
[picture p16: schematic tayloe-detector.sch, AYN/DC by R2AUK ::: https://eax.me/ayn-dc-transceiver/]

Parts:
C8, C9, C10, C11, C12, C14, C15, C16, C17, C19: 0.1u; C_0805_2012Metric_Pad1.15x1.40mm_HandSolder
C13, C18: 0.01u; C_0805_2012Metric_Pad1.15x1.40mm_HandSolder
R6: 22; R_0805_2012Metric_Pad1.15x1.40mm_HandSolder
R7, R8, R10, R13: 300; R_0805_2012Metric_Pad1.15x1.40mm_HandSolder
R9, R11, R12, R14: 10K; R_0805_2012Metric_Pad1.15x1.40mm_HandSolder
R15, R16: 4.7K; R_0805_2012Metric_Pad1.15x1.40mm_HandSolder
T1: FT37-43; DIP-4_W7.62mm
U3: NE5532; SOIC-8_5.23x5.23mm_P1.27mm
U4: FST3253; TSSOP-16_4.4x5mm_P0.65mm
U5: 74AC74; SOIC-14_3.9x8.7mm_P1.27mm

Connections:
+5V: C10.1, C15.1, R11.1, R15.1, U4.16 (VCC), U5.1 (~R), U5.4 (~S), U5.10 (~S), U5.13 (~R), U5.14 (VCC); also elsewhere on the board
+12V: R6.1; also elsewhere on the board
DET_IN: C12.2; also elsewhere on the board
GND: C8.2, C9.2, C10.2, C11.2, C14.2, C15.2, C16.2, C17.2, R12.2, R16.2, T1.4, U3.4 (V-), U4.1 (1~OE), U4.8 (GND), U4.15 (2~OE), U5.7 (GND); also elsewhere on the board
IF_I: C13.1, R9.1, U3.1; also elsewhere on the board
IF_Q: C18.1, R14.1, U3.7; also elsewhere on the board
LO_I: U4.14 (S0), U5.6 (~Q)
LO_Q: U4.2 (S1), U5.2 (D), U5.8 (~Q)
unnamed: C8.1, R6.2, U3.8 (V+)
unnamed: C9.1, R7.2, U4.6 (1B1), U4.10 (2B1)
unnamed: C11.1, R8.2, U4.3 (1B4), U4.13 (2B4)
unnamed: C12.1, T1.1
unnamed: C13.2, R8.1, R9.2, U3.2 (-)
unnamed: C14.1, R10.2, U4.5 (1B2), U4.11 (2B2)
unnamed: C16.1, R11.2, R12.1, T1.3
unnamed: C17.1, R13.2, U4.4 (1B3), U4.12 (2B3)
unnamed: C18.2, R13.1, R14.2, U3.6 (-)
unnamed: C19.1, R15.2, R16.1, U5.3 (C), U5.11 (C)
unnamed: R7.1, U3.3 (+)
unnamed: R10.1, U3.5 (+)
unnamed: T1.2, U4.7 (1A), U4.9 (2A)
unnamed: U5.5 (Q), U5.12 (D)
SI5351_CH2: C19.2; also elsewhere on the board

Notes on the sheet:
Although Si5351 can generate a pair of signals with 90° phase shift changing the frequency requires resetting the PLL. This is a slow operation and causes pops. In theory it’s possible to generate signals with phase shift 90°±5° or so on the frequency range of 70 kHz without changing the PLL settin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
180°
90°
270°
Note: since LO_I and LO_Q are 90° out of phase the switch order is goung to be: B1, B2, B4!, B3
8T bifilar @ FT37-43
Here LO_I is shifted -90° relatively to LO_Q. (The rising edge of LO_I comes first.)
For USB IF_I is shifted +90° relatively to IF_Q. (The rising edge of IF_Q comes first.) For LSB IF_I is shifted -90° relatively to IF_Q. (The rising edge of IF_I comes first.)

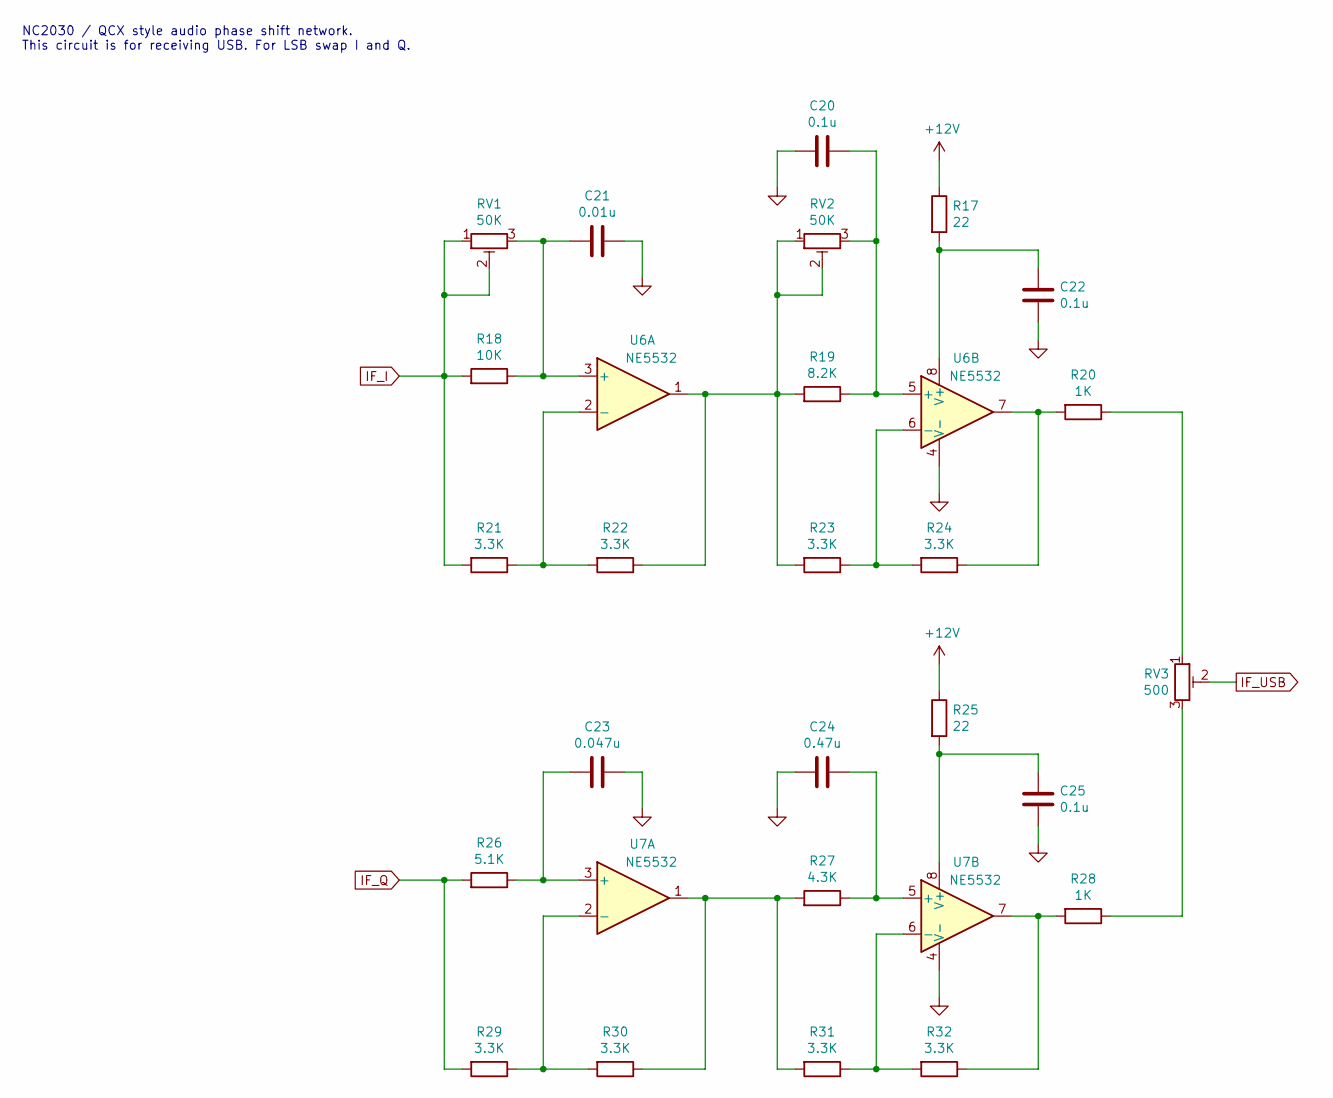
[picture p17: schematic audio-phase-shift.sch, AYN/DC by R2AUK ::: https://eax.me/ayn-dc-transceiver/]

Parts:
C20, C22, C25: 0.1u; C_0805_2012Metric_Pad1.15x1.40mm_HandSolder
C21: 0.01u; C_0805_2012Metric_Pad1.15x1.40mm_HandSolder
C23: 0.047u; C_0805_2012Metric_Pad1.15x1.40mm_HandSolder
C24: 0.47u; C_0805_2012Metric_Pad1.15x1.40mm_HandSolder
R17, R25: 22; R_0805_2012Metric_Pad1.15x1.40mm_HandSolder
R18: 10K; R_0805_2012Metric_Pad1.15x1.40mm_HandSolder
R19: 8.2K; R_0805_2012Metric_Pad1.15x1.40mm_HandSolder
R20, R28: 1K; R_0805_2012Metric_Pad1.15x1.40mm_HandSolder
R21, R22, R23, R24, R29, R30, R31, R32: 3.3K; R_0805_2012Metric_Pad1.15x1.40mm_HandSolder
R26: 5.1K; R_0805_2012Metric_Pad1.15x1.40mm_HandSolder
R27: 4.3K; R_0805_2012Metric_Pad1.15x1.40mm_HandSolder
RV1, RV2: 50K; Potentiometer_Bourns_3296W_Vertical
RV3: 500; Potentiometer_Bourns_3296W_Vertical
U6, U7: NE5532; SOIC-8_5.23x5.23mm_P1.27mm

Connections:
+12V: R17.1, R25.1; also elsewhere on the board
GND: C20.2, C21.1, C22.2, C23.1, C24.2, C25.2, U6.4 (V-), U7.4 (V-); also elsewhere on the board
IF_I: R18.2, R21.2, RV1.1, RV1.2; also elsewhere on the board
IF_Q: R26.2, R29.2; also elsewhere on the board
IF_USB: RV3.2; also elsewhere on the board
unnamed: C20.1, R19.1, RV2.3, U6.5 (+)
unnamed: C21.2, R18.1, RV1.3, U6.3 (+)
unnamed: C22.1, R17.2, U6.8 (V+)
unnamed: C23.2, R26.1, U7.3 (+)
unnamed: C24.1, R27.1, U7.5 (+)
unnamed: C25.1, R25.2, U7.8 (V+)
unnamed: R19.2, R22.1, R23.2, RV2.1, RV2.2, U6.1
unnamed: R20.1, RV3.1
unnamed: R20.2, R24.1, U6.7
unnamed: R21.1, R22.2, U6.2 (-)
unnamed: R23.1, R24.2, U6.6 (-)
unnamed: R27.2, R30.1, R31.2, U7.1
unnamed: R28.1, RV3.3
unnamed: R28.2, R32.1, U7.7
unnamed: R29.1, R30.2, U7.2 (-)
unnamed: R31.1, R32.2, U7.6 (-)

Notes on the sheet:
NC2030 / QCX style audio phase shift network. This circuit is for receiving USB. For LSB swap I and Q.

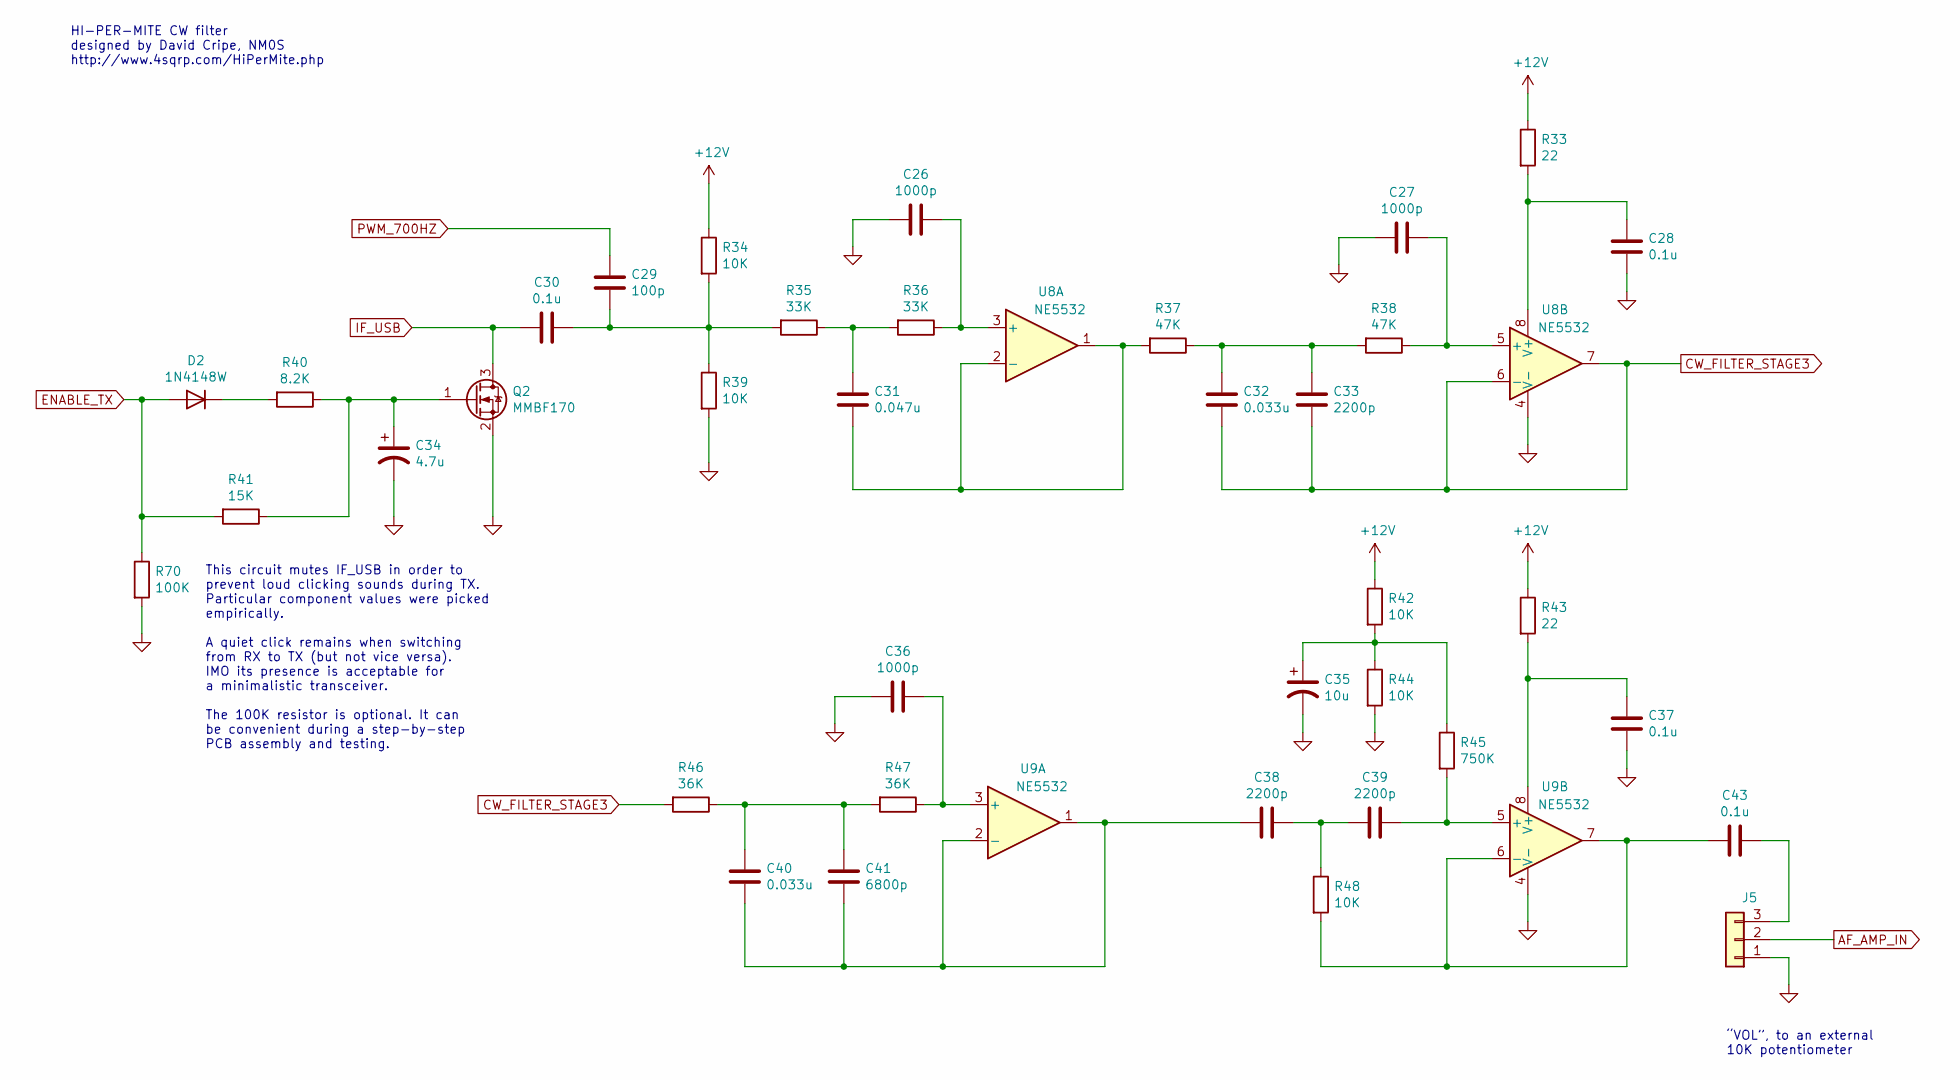
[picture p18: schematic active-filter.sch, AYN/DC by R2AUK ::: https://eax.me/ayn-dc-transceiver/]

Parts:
C26, C27, C36: 1000p; C_0805_2012Metric_Pad1.15x1.40mm_HandSolder
C28, C30, C37, C43: 0.1u; C_0805_2012Metric_Pad1.15x1.40mm_HandSolder
C29: 100p; C_0805_2012Metric_Pad1.15x1.40mm_HandSolder
C31: 0.047u; C_0805_2012Metric_Pad1.15x1.40mm_HandSolder
C32, C40: 0.033u; C_0805_2012Metric_Pad1.15x1.40mm_HandSolder
C33, C38, C39: 2200p; C_0805_2012Metric_Pad1.15x1.40mm_HandSolder
C34: 4.7u; CP_Elec_4x5.4
C35: 10u; CP_Elec_4x5.4
C41: 6800p; C_0805_2012Metric_Pad1.15x1.40mm_HandSolder
D2: 1N4148W; D_SOD-123
J5: Conn_01x03; PinSocket_1x03_P2.54mm_Vertical
Q2: MMBF170; SOT-23
R33, R43: 22; R_0805_2012Metric_Pad1.15x1.40mm_HandSolder
R34, R39, R42, R44, R48: 10K; R_0805_2012Metric_Pad1.15x1.40mm_HandSolder
R35, R36: 33K; R_0805_2012Metric_Pad1.15x1.40mm_HandSolder
R37, R38: 47K; R_0805_2012Metric_Pad1.15x1.40mm_HandSolder
R40: 8.2K; R_0805_2012Metric_Pad1.15x1.40mm_HandSolder
R41: 15K; R_0805_2012Metric_Pad1.15x1.40mm_HandSolder
R45: 750K; R_0805_2012Metric_Pad1.15x1.40mm_HandSolder
R46, R47: 36K; R_0805_2012Metric_Pad1.15x1.40mm_HandSolder
R70: 100K; R_0805_2012Metric_Pad1.15x1.40mm_HandSolder
U8, U9: NE5532; SOIC-8_5.23x5.23mm_P1.27mm

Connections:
+12V: R33.1, R34.1, R42.1, R43.1; also elsewhere on the board
AF_AMP_IN: J5.2; also elsewhere on the board
CW_FILTER_STAGE3: C32.2, C33.2, R46.2, U8.6 (-), U8.7
ENABLE_TX: D2.2 (A), R41.2, R70.1; also elsewhere on the board
GND: C26.2, C27.2, C28.2, C34.2, C35.2, C36.2, C37.2, J5.1, Q2.2 (S), R39.2, R44.2, R70.2, U8.4 (V-), U9.4 (V-); also elsewhere on the board
IF_USB: C30.2, Q2.3 (D); also elsewhere on the board
unnamed: C26.1, R36.1, U8.3 (+)
unnamed: C27.1, R38.1, U8.5 (+)
unnamed: C28.1, R33.2, U8.8 (V+)
unnamed: C29.2, C30.1, R34.2, R35.2, R39.1
unnamed: C31.1, R35.1, R36.2
unnamed: C31.2, R37.2, U8.1, U8.2 (-)
unnamed: C32.1, C33.1, R37.1, R38.2
unnamed: C34.1, Q2.1 (G), R40.1, R41.1
unnamed: C35.1, R42.2, R44.1, R45.1
unnamed: C36.1, R47.1, U9.3 (+)
unnamed: C37.1, R43.2, U9.8 (V+)
unnamed: C38.1, C39.2, R48.1
unnamed: C38.2, C40.2, C41.2, U9.1, U9.2 (-)
unnamed: C39.1, R45.2, U9.5 (+)
unnamed: C40.1, C41.1, R46.1, R47.2
unnamed: C43.1, J5.3
unnamed: C43.2, R48.2, U9.6 (-), U9.7
unnamed: D2.1 (K), R40.2
PWM_700HZ: C29.1; also elsewhere on the board

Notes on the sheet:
HI-PER-MITE CW filter designed by David Cripe, NM0S http://www.4sqrp.com/HiPerMite.php
“VOL”, to an external 10K potentiometer
This circuit mutes IF_USB in order to prevent loud clicking sounds during TX. Particular component values were picked empirically. A quiet click remains when switching from RX to TX (but not vice versa). IMO its presence is acceptable for a minimalistic transceiver. The 100K resistor is optional. I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

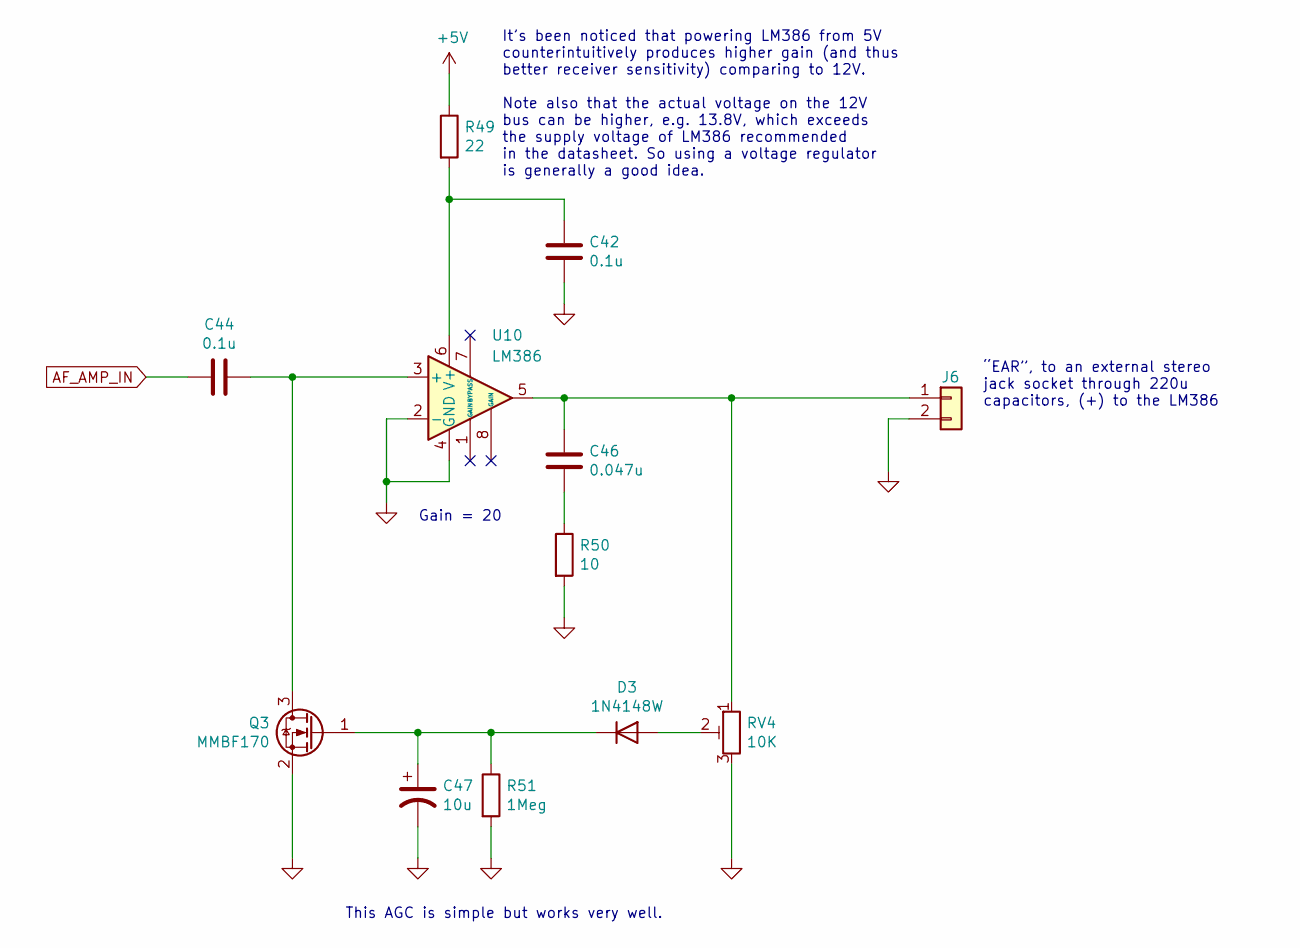
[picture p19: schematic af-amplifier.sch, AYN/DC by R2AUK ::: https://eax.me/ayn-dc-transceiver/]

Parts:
C42, C44: 0.1u; C_0805_2012Metric_Pad1.15x1.40mm_HandSolder
C46: 0.047u; C_0805_2012Metric_Pad1.15x1.40mm_HandSolder
C47: 10u; CP_Elec_4x5.4
D3: 1N4148W; D_SOD-123
J6: Conn_01x02; PinSocket_1x02_P2.54mm_Vertical
Q3: MMBF170; SOT-23
R49: 22; R_0805_2012Metric_Pad1.15x1.40mm_HandSolder
R50: 10; R_0805_2012Metric_Pad1.15x1.40mm_HandSolder
R51: 1Meg; R_0805_2012Metric_Pad1.15x1.40mm_HandSolder
RV4: 10K; Potentiometer_Bourns_3296W_Vertical
U10: LM386; SO-8_5.3x6.2mm_P1.27mm

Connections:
+5V: R49.1; also elsewhere on the board
AF_AMP_IN: C44.2; also elsewhere on the board
GND: C42.2, C47.2, J6.2, Q3.2 (S), R50.2, R51.2, RV4.3, U10.2 (-), U10.4 (GND); also elsewhere on the board
unnamed: C42.1, R49.2, U10.6 (V+)
unnamed: C44.1, Q3.3 (D), U10.3 (+)
unnamed: C46.1, J6.1, RV4.1, U10.5
unnamed: C46.2, R50.1
unnamed: C47.1, D3.1 (K), Q3.1 (G), R51.1
unnamed: D3.2 (A), RV4.2

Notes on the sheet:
“EAR”, to an external stereo jack socket through 220u capacitors, (+) to the LM386
It’s been noticed that powering LM386 from 5V counterintuitively produces higher gain (and thus better receiver sensitivity) comparing to 12V. Note also that the actual voltage on the 12V bus can be higher, e.g. 13.8V, which exceeds the supply voltage of LM386 recommended in the datasheet. So using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
Gain = 20
This AGC is simple but works very well.

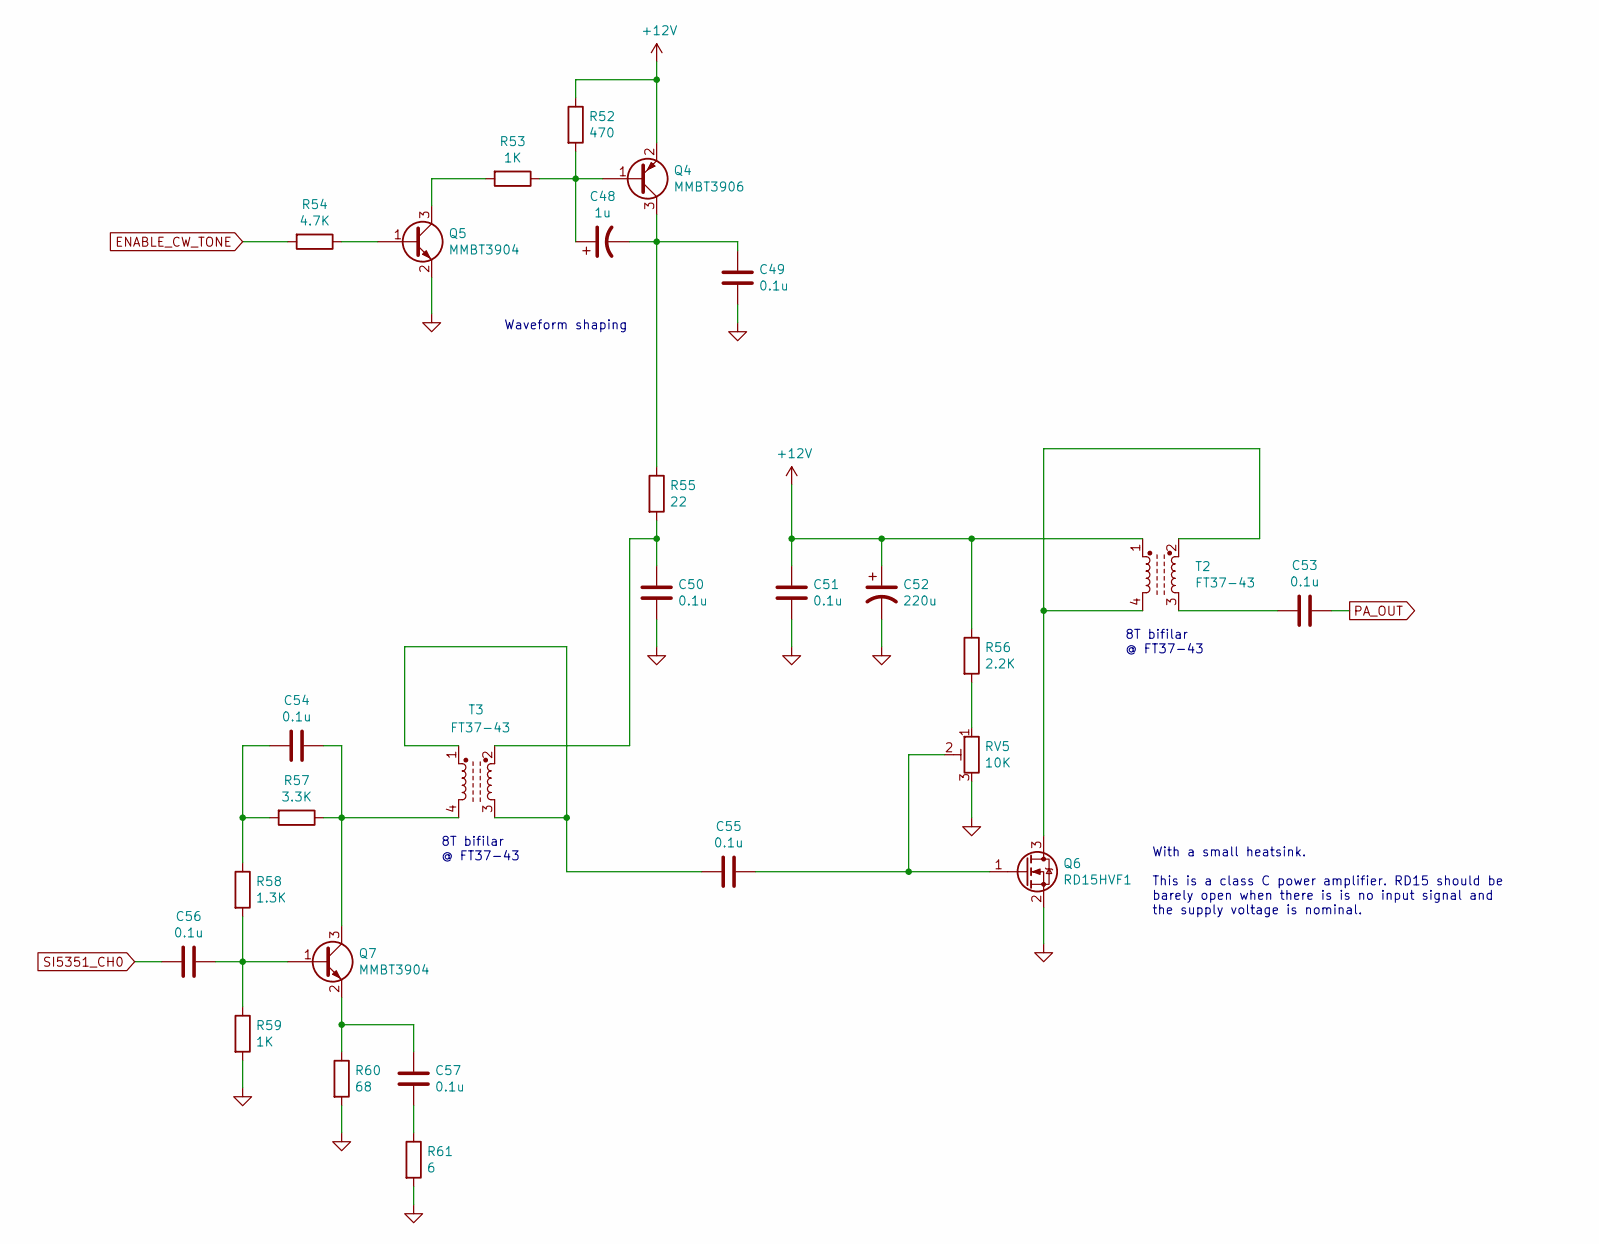
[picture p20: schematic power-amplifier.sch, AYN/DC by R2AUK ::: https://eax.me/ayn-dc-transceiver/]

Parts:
C48: 1u; CP_Elec_4x5.4
C49, C50, C51, C53, C54, C55, C56, C57: 0.1u; C_0805_2012Metric_Pad1.15x1.40mm_HandSolder
C52: 220u; CP_Elec_8x10.5
Q4: MMBT3906; SOT-23
Q5, Q7: MMBT3904; SOT-23
Q6: RD15HVF1; TO-220-3_Vertical
R52: 470; R_0805_2012Metric_Pad1.15x1.40mm_HandSolder
R53, R59: 1K; R_0805_2012Metric_Pad1.15x1.40mm_HandSolder
R54: 4.7K; R_0805_2012Metric_Pad1.15x1.40mm_HandSolder
R55: 22; R_0805_2012Metric_Pad1.15x1.40mm_HandSolder
R56: 2.2K; R_0805_2012Metric_Pad1.15x1.40mm_HandSolder
R57: 3.3K; R_0805_2012Metric_Pad1.15x1.40mm_HandSolder
R58: 1.3K; R_0805_2012Metric_Pad1.15x1.40mm_HandSolder
R60: 68; R_0805_2012Metric_Pad1.15x1.40mm_HandSolder
R61: 6; R_0805_2012Metric_Pad1.15x1.40mm_HandSolder
RV5: 10K; Potentiometer_Bourns_3296W_Vertical
T2, T3: FT37-43; DIP-4_W7.62mm

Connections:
+12V: C51.1, C52.1, Q4.2 (E), R52.1, R56.1, T2.1; also elsewhere on the board
ENABLE_CW_TONE: R54.2; also elsewhere on the board
GND: C49.2, C50.2, C51.2, C52.2, Q5.2 (E), Q6.2 (S), R59.2, R60.2, R61.2, RV5.3; also elsewhere on the board
unnamed: C48.1, Q4.1 (B), R52.2, R53.1
unnamed: C48.2, C49.1, Q4.3 (C), R55.1
unnamed: C50.1, R55.2, T3.2
unnamed: C53.2, T2.3
unnamed: C54.1, Q7.3 (C), R57.1, T3.4
unnamed: C54.2, R57.2, R58.1
unnamed: C55.1, Q6.1 (G), RV5.2
unnamed: C55.2, T3.1, T3.3
unnamed: C56.1, Q7.1 (B), R58.2, R59.1
unnamed: C57.1, Q7.2 (E), R60.1
unnamed: C57.2, R61.1
unnamed: Q5.1 (B), R54.1
unnamed: Q5.3 (C), R53.2
unnamed: Q6.3 (D), T2.2, T2.4
unnamed: R56.2, RV5.1
PA_OUT: C53.1; also elsewhere on the board
SI5351_CH0: C56.2; also elsewhere on the board

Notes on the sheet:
8T bifilar @ FT37-43
With a small heatsink. This is a class C power amplifier. RD15 should be barely open when there is is no input signal and the supply voltage is nominal.
Waveform shaping

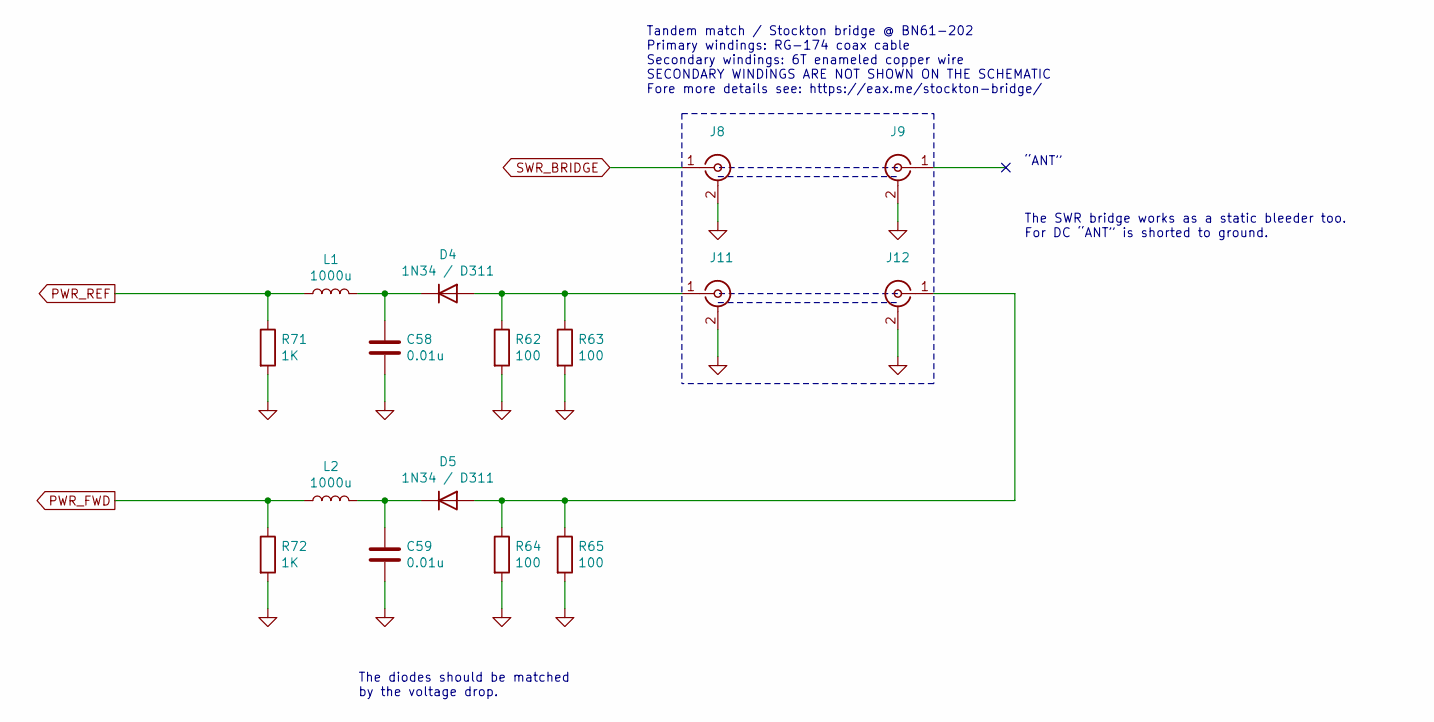
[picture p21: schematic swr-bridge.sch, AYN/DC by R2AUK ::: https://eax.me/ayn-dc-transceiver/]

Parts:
C58, C59: 0.01u; C_0805_2012Metric_Pad1.15x1.40mm_HandSolder
D4, D5: 1N34 / D311; D_DO-41_SOD81_P3.81mm_Vertical_AnodeUp
J8, J9, J11, J12: Conn_Coaxial; PinSocket_1x02_P2.54mm_Vertical
L1, L2: 1000u; L_Axial_L6.6mm_D2.7mm_P10.16mm_Horizontal_Vishay_IM-2
R62, R63, R64, R65: 100; R_0805_2012Metric_Pad1.15x1.40mm_HandSolder
R71, R72: 1K; R_0805_2012Metric_Pad1.15x1.40mm_HandSolder

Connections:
GND: C58.2, C59.2, J8.2 (Ext), J9.2 (Ext), J11.2 (Ext), J12.2 (Ext), R62.2, R63.2, R64.2, R65.2, R71.2, R72.2; also elsewhere on the board
unnamed: C58.1, D4.1 (K), L1.2
unnamed: C59.1, D5.1 (K), L2.2
unnamed: D4.2 (A), J11.1 (In), R62.1, R63.1
unnamed: D5.2 (A), J12.1 (In), R64.1, R65.1
PWR_FWD: L2.1, R72.1; also elsewhere on the board
PWR_REF: L1.1, R71.1; also elsewhere on the board
SWR_BRIDGE: J8.1 (In); also elsewhere on the board

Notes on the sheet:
“ANT”
The SWR bridge works as a static bleeder too. For DC “ANT” is shorted to ground.
Tandem match / Stockton bridge @ BN61-202 Primary windings: RG-174 coax cable Secondary windings: 6T enameled copper wire SECONDARY WINDINGS ARE NOT SHOWN ON THE SCHEMATIC Fore more details see: https://eax.me/stockton-bridge/
The diodes should be matched by the voltage drop.

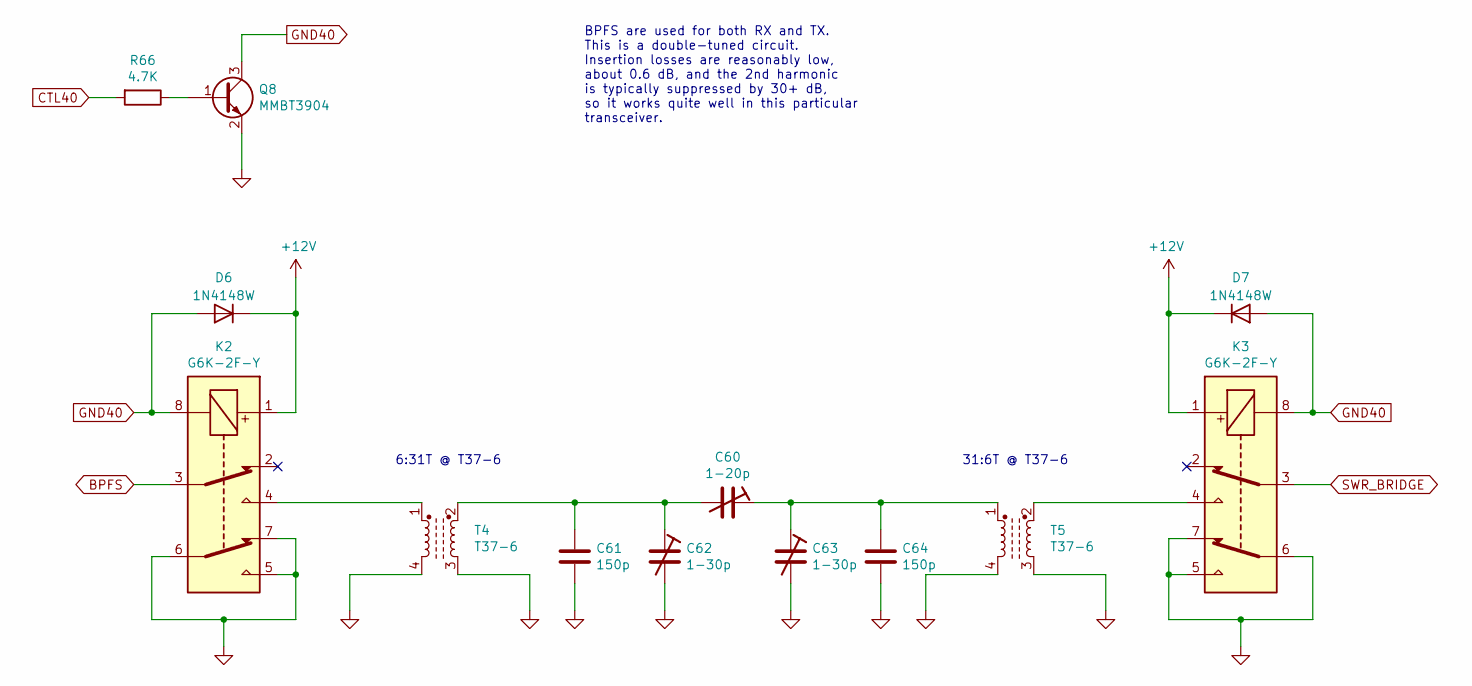
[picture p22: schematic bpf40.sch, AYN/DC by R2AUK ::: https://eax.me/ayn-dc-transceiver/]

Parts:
C60: 1-20p; C_Trim_THD_L7.0mm_W6.5mm_P5.00mm
C61, C64: 150p; C_0805_2012Metric_Pad1.15x1.40mm_HandSolder
C62, C63: 1-30p; C_Trim_THD_L7.0mm_W6.5mm_P5.00mm
D6, D7: 1N4148W; D_SOD-123
K2, K3: G6K-2F-Y; Relay_DPDT_Omron_G6K-2F-Y
Q8: MMBT3904; SOT-23
R66: 4.7K; R_0805_2012Metric_Pad1.15x1.40mm_HandSolder
T4, T5: T37-6; DIP-4_W7.62mm

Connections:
+12V: D6.1 (K), D7.1 (K), K2.1, K3.1; also elsewhere on the board
BPFS: K2.3; also elsewhere on the board
CTL40: R66.2; also elsewhere on the board
GND: C61.2, C62.2, C63.2, C64.2, K2.5, K2.6, K2.7, K3.5, K3.6, K3.7, Q8.2 (E), T4.3, T4.4, T5.3, T5.4; also elsewhere on the board
GND40: D6.2 (A), D7.2 (A), K2.8, K3.8, Q8.3 (C)
unnamed: C60.1, C63.1, C64.1, T5.1
unnamed: C60.2, C61.1, C62.1, T4.2
unnamed: K2.4, T4.1
unnamed: K3.4, T5.2
unnamed: Q8.1 (B), R66.1
SWR_BRIDGE: K3.3; also elsewhere on the board

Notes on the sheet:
6:31T @ T37-6
31:6T @ T37-6
BPFS are used for both RX and TX. This is a double-tuned circuit. Insertion losses are reasonably low, about 0.6 dB, and the 2nd harmonic is typically suppressed by 30+ dB, so it works quite well in this particular transceiver.

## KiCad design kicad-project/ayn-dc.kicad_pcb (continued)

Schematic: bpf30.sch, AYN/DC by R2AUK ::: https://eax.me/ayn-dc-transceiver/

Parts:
C65: 1-10p; C_Trim_THD_L7.0mm_W6.5mm_P5.00mm
C66, C69: 100p; C_0805_2012Metric_Pad1.15x1.40mm_HandSolder
C67, C68: 1-30p; C_Trim_THD_L7.0mm_W6.5mm_P5.00mm
D8, D9: 1N4148W; D_SOD-123
K4, K5: G6K-2F-Y; Relay_DPDT_Omron_G6K-2F-Y
Q9: MMBT3904; SOT-23
R67: 4.7K; R_0805_2012Metric_Pad1.15x1.40mm_HandSolder
T6, T7: T37-6; DIP-4_W7.62mm

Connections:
+12V: D8.1 (K), D9.1 (K), K4.1, K5.1; also elsewhere on the board
BPFS: K4.3; also elsewhere on the board
CTL30: R67.2; also elsewhere on the board
GND: C66.2, C67.2, C68.2, C69.2, K4.5, K4.6, K4.7, K5.5, K5.6, K5.7, Q9.2 (E), T6.3, T6.4, T7.3, T7.4; also elsewhere on the board
GND30: D8.2 (A), D9.2 (A), K4.8, K5.8, Q9.3 (C)
unnamed: C65.1, C68.1, C69.1, T7.1
unnamed: C65.2, C66.1, C67.1, T6.2
unnamed: K4.4, T6.1
unnamed: K5.4, T7.2
unnamed: Q9.1 (B), R67.1
SWR_BRIDGE: K5.3; also elsewhere on the board

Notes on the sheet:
5:25T @ T37-6
25:5T @ T37-6

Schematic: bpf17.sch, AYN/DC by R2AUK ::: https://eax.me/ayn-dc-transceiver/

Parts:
C70: 1-10p; C_Trim_THD_L7.0mm_W6.5mm_P5.00mm
C71, C74: 47p; C_0805_2012Metric_Pad1.15x1.40mm_HandSolder
C72, C73: 1-30p; C_Trim_THD_L7.0mm_W6.5mm_P5.00mm
D10, D11: 1N4148W; D_SOD-123
K6, K7: G6K-2F-Y; Relay_DPDT_Omron_G6K-2F-Y
Q10: MMBT3904; SOT-23
R68: 4.7K; R_0805_2012Metric_Pad1.15x1.40mm_HandSolder
T8, T9: T37-6; DIP-4_W7.62mm

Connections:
+12V: D10.1 (K), D11.1 (K), K6.1, K7.1; also elsewhere on the board
BPFS: K6.3; also elsewhere on the board
CTL17: R68.2; also elsewhere on the board
GND: C71.2, C72.2, C73.2, C74.2, K6.5, K6.6, K6.7, K7.5, K7.6, K7.7, Q10.2 (E), T8.3, T8.4, T9.3, T9.4; also elsewhere on the board
GND17: D10.2 (A), D11.2 (A), K6.8, K7.8, Q10.3 (C)
unnamed: C70.1, C73.1, C74.1, T9.1
unnamed: C70.2, C71.1, C72.1, T8.2
unnamed: K6.4, T8.1
unnamed: K7.4, T9.2
unnamed: Q10.1 (B), R68.1
SWR_BRIDGE: K7.3; also elsewhere on the board

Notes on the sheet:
3:19T @ T37-6
19:3T @ T37-6

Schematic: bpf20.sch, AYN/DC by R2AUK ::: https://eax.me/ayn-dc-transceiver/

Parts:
C75: 1-10p; C_Trim_THD_L7.0mm_W6.5mm_P5.00mm
C76, C79: 68p; C_0805_2012Metric_Pad1.15x1.40mm_HandSolder
C77, C78: 1-30p; C_Trim_THD_L7.0mm_W6.5mm_P5.00mm
D12, D13: 1N4148W; D_SOD-123
K8, K9: G6K-2F-Y; Relay_DPDT_Omron_G6K-2F-Y
Q11: MMBT3904; SOT-23
R69: 4.7K; R_0805_2012Metric_Pad1.15x1.40mm_HandSolder
T10, T11: T37-6; DIP-4_W7.62mm

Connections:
+12V: D12.1 (K), D13.1 (K), K8.1, K9.1; also elsewhere on the board
BPFS: K8.3; also elsewhere on the board
CTL20: R69.2; also elsewhere on the board
GND: C76.2, C77.2, C78.2, C79.2, K8.5, K8.6, K8.7, K9.5, K9.6, K9.7, Q11.2 (E), T10.3, T10.4, T11.3, T11.4; also elsewhere on the board
GND20: D12.2 (A), D13.2 (A), K8.8, K9.8, Q11.3 (C)
unnamed: C75.1, C78.1, C79.1, T11.1
unnamed: C75.2, C76.1, C77.1, T10.2
unnamed: K8.4, T10.1
unnamed: K9.4, T11.2
unnamed: Q11.1 (B), R69.1
SWR_BRIDGE: K9.3; also elsewhere on the board

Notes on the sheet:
4:21T @ T37-6
21:4T @ T37-6

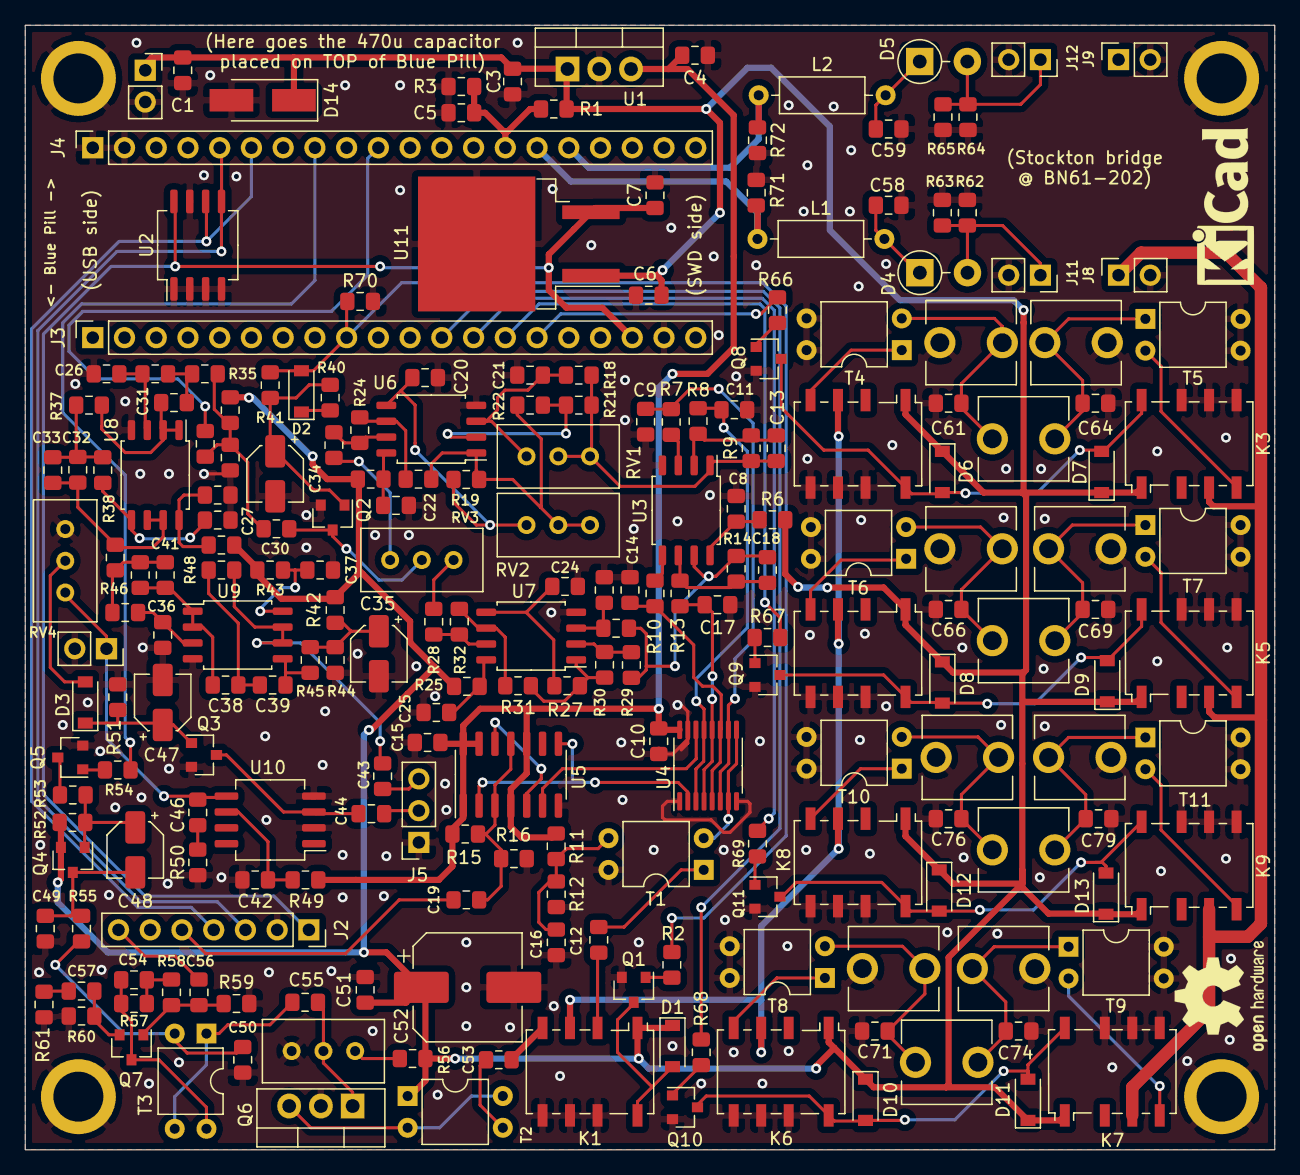
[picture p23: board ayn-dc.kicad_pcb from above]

Board: 2 copper layers, 100.0 x 90.0 mm, 226 parts (0 on the bottom side), 128 nets.

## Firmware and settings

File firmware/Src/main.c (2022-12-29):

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

/* Includes ------------------------------------------------------------------*/
#include "main.h"

/* USER CODE BEGIN Includes */
#include <string.h>
#include <stdlib.h>
#include <stdbool.h>
#include "si5351.h"
#include "lcd.h"

/* USER CODE END Includes */

ADC_HandleTypeDef hadc1;

I2C_HandleTypeDef hi2c2;

TIM_HandleTypeDef htim1;
TIM_HandleTypeDef htim2;
TIM_HandleTypeDef htim3;

/* USER CODE BEGIN PV */

/* USER CODE END PV */

void SystemClock_Config(void);
static void MX_GPIO_Init(void);
static void MX_TIM1_Init(void);
static void MX_TIM2_Init(void);
static void MX_ADC1_Init(void);
static void MX_TIM3_Init(void);
static void MX_I2C2_Init(void);
/* USER CODE BEGIN PFP */

/* USER CODE END PFP */

/* USER CODE BEGIN 0 */

#define CH_CW   0
#define CH_CAL  1
#define CH_VFO  2

const int32_t CW_PITCH = 700;
const int32_t si5351_correction = 5188;

/* Adjust for used rotary encoders */
#define MAIN_DELTA_DIV    1
#define MAIN_DELTA_MULT   1
#define MULTI_DELTA_DIV   1
#define MULTI_DELTA_MULT  1

int32_t Fvfo = 1000000; // dummy value, will be changed below

const uint8_t eeprom_i2c_addr = (0x50 << 1);
#define KEYER_CONFIG_EEPROM_ADDR        0x0000

typedef enum {
    CLAR_MODE_DISABLED = 0,
    CLAR_MODE_RIT = 1,
    CLAR_MODE_XIT = 2,
} ClarMode_t;

bool lockMode = false;
bool fastMode = false;
bool bandMode = false;
ClarMode_t clarMode = CLAR_MODE_DISABLED;

int32_t clarOffset = 0;

int32_t sendStart = 0;
int32_t sendFinish = 0;
int32_t keyReadTimeout = 0;
int32_t sendTimeout = 0;
bool isSending = false;

typedef enum {
    CW_SEND_NONE = 0,
    CW_SEND_DIT = 1,
    CW_SEND_DAH = 2,
} CwSend_t;

CwSend_t lastSent = CW_SEND_NONE;
CwSend_t nextSend = CW_SEND_NONE;

typedef struct {
    uint16_t checksum;
    bool straightKey;
    int32_t speedWPM;
    int32_t ditTimeMs;
} KeyerConfig_t;

KeyerConfig_t keyerConfig = {
    .checksum = 0,
    .straightKey = false,
    .speedWPM = 19,

    // ditTimeMs = 60*1000/(50*WPM)
    // where 50 is the length in dits of "PARIS "
    // see https://morsecode.world/international/timing.html
    .ditTimeMs = 63,
};

bool inTransmitMode = false;
bool inCWTrainerMode = false;

#define BUTTON_DEBOUNCE_TIME_MS 200
typedef enum {
    BUTTON_STATUS_PRESSED = 0,
    BUTTON_STATUS_RELEASED = 1,
    BUTTON_STATUS_DEBOUNCE = 2,
} ButtonStatus_t;

typedef enum {
    USE_LPF_80 = 0,
    USE_LPF_40 = 1,
    USE_LPF_30 = 2,
    USE_LPF_20 = 3,
    USE_LPF_17 = 4,
    USE_LPF_15 = 5,
    USE_LPF_12 = 6,
    USE_LPF_10 = 7,
} UseLPF_t;

typedef struct {
    int32_t minFreq;
    int32_t maxFreq;
    int32_t lastFreq;
    UseLPF_t lpf;
    /*
     * Compensate for losses in RG-174, frequency response of the given
     * PA depending on the used transistor, imperfections of the LPFs, etc.
     */
    si5351DriveStrength_t txDriveStrength;
} BandInfo_t;

int32_t currentBand = 2; // default: 20m

BandInfo_t bands[] = {
/*   
    {
        .minFreq  = 3500000,
        .maxFreq  = 3570000,
        .lastFreq = 3560000,
        .lpf = USE_LPF_80,
        .txDriveStrength = SI5351_DRIVE_STRENGTH_2MA,
    },
*/
    {
        .minFreq  = 7000000,
        .maxFreq  = 7040000,
        .lastFreq = 7030000,
        .lpf = USE_LPF_40,
        .txDriveStrength = SI5351_DRIVE_STRENGTH_2MA,
    },
    {
        .minFreq  = 10100000,
        .maxFreq  = 10130000,
        .lastFreq = 10116000,
        .lpf = USE_LPF_30,
        .txDriveStrength = SI5351_DRIVE_STRENGTH_2MA,
    },
    {
        .minFreq  = 14000000,
        .maxFreq  = 14070000,
        .lastFreq = 14060000,
        .lpf = USE_LPF_20,
        .txDriveStrength = SI5351_DRIVE_STRENGTH_2MA,
    },
    {
        .minFreq  = 18068000,
        .maxFreq  = 18095000,
        .lastFreq = 18086000,
        .lpf = USE_LPF_17,
        .txDriveStrength = SI5351_DRIVE_STRENGTH_2MA,
    },
/*
    {
        .minFreq  = 21000000,
        .maxFreq  = 21070000,
        .lastFreq = 21060000,
        .lpf = USE_LPF_15,
        .txDriveStrength = SI5351_DRIVE_STRENGTH_2MA,
    },
    {
        .minFreq  = 24890000,
        .maxFreq  = 24915000,
        .lastFreq = 24906000,
        .lpf = USE_LPF_12,
        .txDriveStrength = SI5351_DRIVE_STRENGTH_2MA,
    },
    {
        .minFreq  = 28000000,
        .maxFreq  = 28070000,
        .lastFreq = 28060000,
        .lpf = USE_LPF_10,
        .txDriveStrength = SI5351_DRIVE_STRENGTH_2MA,
    },
*/
};

void ADC_Select_Channel(uint32_t ch) {
    ADC_ChannelConfTypeDef conf = {
        .Channel = ch,
        .Rank = 1,
        .SamplingTime = ADC_SAMPLETIME_28CYCLES_5,
    };
    if (HAL_ADC_ConfigChannel(&hadc1, &conf) != HAL_OK) {
        Error_Handler();
    }
} 

double ADC_ReadVoltage(uint32_t ch) {
    ADC_Select_Channel(ch);
    HAL_ADC_PollForConversion(&hadc1, HAL_MAX_DELAY);
    return ((double)HAL_ADC_GetValue(&hadc1))*3.3/4096.0;
}

// http://en.wikipedia.org/wiki/Jenkins_hash_function
uint32_t jenkinsHash(const uint8_t *data, const size_t len) {
  uint32_t hash, i;
  for(hash = i = 0; i < len; ++i) {
    hash += data[i];
    hash += (hash << 10);
    hash ^= (hash >> 6);
  }
  hash += (hash << 3);
  hash ^= (hash >> 11);
  hash += (hash << 15);
  return hash;
}

void loadKeyerConfig() {
    HAL_StatusTypeDef status;
    uint16_t savedChecksum;
    uint32_t attempt = 0;
    KeyerConfig_t savedKeyerConfig;

    for(;;) {
        status = HAL_I2C_IsDeviceReady(&hi2c2, eeprom_i2c_addr, 3, HAL_MAX_DELAY);
        if(status == HAL_OK)
            break;

        attempt++;
        if(attempt == 10)
        {
            LCD_Goto(0, 0);
            LCD_SendString(" EEPROM ");
            LCD_Goto(1, 0);
            LCD_SendString(" ERROR! ");
            HAL_Delay(2000);
            LCD_Clear();
            return;
        }
    }

    HAL_I2C_Mem_Read(&hi2c2, eeprom_i2c_addr, KEYER_CONFIG_EEPROM_ADDR, I2C_MEMADD_SIZE_16BIT,
        (uint8_t*)&savedKeyerConfig, sizeof(savedKeyerConfig), HAL_MAX_DELAY);

    savedChecksum = savedKeyerConfig.checksum;
    savedKeyerConfig.checksum = 0;

    if((jenkinsHash((const uint8_t*)&savedKeyerConfig, sizeof(savedKeyerConfig)) & 0xFFFF) == savedChecksum) {
        keyerConfig = savedKeyerConfig;
    } else {
        LCD_Goto(0, 0);
        LCD_SendString("CHECKSUM");
        LCD_Goto(1, 0);
        LCD_SendString(" ERROR! ");
        HAL_Delay(2000);
        LCD_Clear();
    }
}

void saveKeyerConfig() {
    HAL_StatusTypeDef status;
    uint16_t checksum;
    keyerConfig.checksum = 0;

    checksum = (jenkinsHash((const uint8_t*)&keyerConfig, sizeof(keyerConfig)) & 0xFFFF);
    keyerConfig.checksum = checksum;

    for(;;) {
        status = HAL_I2C_IsDeviceReady(&hi2c2, eeprom_i2c_addr, 3, HAL_MAX_DELAY);
        if(status == HAL_OK)
            break;
    }

    HAL_I2C_Mem_Write(&hi2c2, eeprom_i2c_addr, KEYER_CONFIG_EEPROM_ADDR, I2C_MEMADD_SIZE_16BIT,
        (uint8_t*)&keyerConfig, sizeof(keyerConfig), HAL_MAX_DELAY);
}

void changeKeyerSpeed(int32_t delta) {
    keyerConfig.speedWPM += delta;
    if(keyerConfig.speedWPM < 10) {
        keyerConfig.speedWPM = 9;
        keyerConfig.straightKey = true;
        keyerConfig.ditTimeMs = 60*1000/(50*16); // as for 16 WPM
    } else {
        keyerConfig.straightKey = false;
        if(keyerConfig.speedWPM > 30) {
            keyerConfig.speedWPM = 30;
        }

        /* +1 compensates the signal rise/fall time */
        keyerConfig.ditTimeMs = 60*1000/(50*(keyerConfig.speedWPM + 1));
    }
}

void SetupCLK(uint8_t output, int32_t Fclk, si5351DriveStrength_t driveStrength) {
    static bool pllSetupDone = false;
    si5351PLLConfig_t pll_conf;
    si5351OutputConfig_t out_conf;

    si5351_Calc(Fclk, &pll_conf, &out_conf);
    if(!pllSetupDone) {
        si5351_SetupPLL(SI5351_PLL_A, &pll_conf);
        pllSetupDone = true;
    }
    si5351_SetupOutput(output, SI5351_PLL_A, driveStrength, &out_conf);
}

void enableTx(bool enable) {
    HAL_GPIO_WritePin(GPIOA, GPIO_PIN_12, enable ? GPIO_PIN_SET : GPIO_PIN_RESET);
}

void changeFrequency(int32_t delta, bool force) {
    static int32_t prevFvfo = 0;

    if((!force) && lockMode) {
        return;
    }

    if(fastMode) {
        delta *= 10;
    }
    bands[currentBand].lastFreq += 100*delta;
    if(fastMode && (delta != 0)) {
        bands[currentBand].lastFreq -= bands[currentBand].lastFreq % 1000;
    }

    if(bands[currentBand].lastFreq < bands[currentBand].minFreq) {
        bands[currentBand].lastFreq = bands[currentBand].minFreq;
    } else if(bands[currentBand].lastFreq > bands[currentBand].maxFreq) {
        bands[currentBand].lastFreq = bands[currentBand].maxFreq;
    }

    Fvfo = bands[currentBand].lastFreq - CW_PITCH;

    if((clarMode == CLAR_MODE_RIT) && (clarOffset != 0)) {
        Fvfo += clarOffset;
    } else {
        // There can be a few spurious signals in this rig.
        // They can be masked like this if necessary:

        /*
        if((bands[currentBand].lastFreq == 18069400) ||
           (bands[currentBand].lastFreq == 18092100)) {
            Fvfo += 50;
        }
        */
    }

    Fvfo *= 4;

    if(force || (Fvfo != prevFvfo)) {
        SetupCLK(CH_VFO, Fvfo, SI5351_DRIVE_STRENGTH_4MA);
    }

    prevFvfo = Fvfo;
}

void displayKeyerSettings() {
    char buff[16];
    if(keyerConfig.straightKey) {
        LCD_Goto(0, 0);
        LCD_SendString("SPEED --");
        LCD_Goto(1, 0);
        LCD_SendString("STRAIGHT");
    } else {
        snprintf(buff, sizeof(buff), "SPEED %02ld", keyerConfig.speedWPM);
        LCD_Goto(0, 0);
        LCD_SendString(buff);
        LCD_Goto(1, 0);
        LCD_SendString("IAMBIC  ");
    }
}

void displayFrequency() {
    char buff[16];
    snprintf(buff, sizeof(buff), "%02ld.%03ld.%01ld",
        bands[currentBand].lastFreq / 1000000,
        (bands[currentBand].lastFreq % 1000000) / 1000,
        (bands[currentBand].lastFreq % 1000) / 100);

    LCD_Goto(0, 0);
    LCD_SendString(buff);
}

bool buttonDitPressed() {
    return (HAL_GPIO_ReadPin(GPIOB, GPIO_PIN_12) == GPIO_PIN_RESET);
}

bool buttonDahPressed() {
    return (HAL_GPIO_ReadPin(GPIOB, GPIO_PIN_13) == GPIO_PIN_RESET);
}

void displayVoltageOrMode(bool force) {
    static double prevVoltage = 0.0;
    static uint32_t lastVoltageUpdateTime = 0;
    // don't forget to add '-u _printf_float' to LDFLAGS
    char buff[16];

    if(force) {
        LCD_Goto(1, 0);
        if(fastMode) {
            LCD_SendString("= FAST =");
            return;
        } else if(lockMode) {
            LCD_SendString("= LOCK =");
            return;
        } else if(bandMode) {
            LCD_SendString("= BAND =");
            return;
        } else if(clarMode != CLAR_MODE_DISABLED) {
            snprintf(buff, sizeof(buff), "%s%s%04d",
                clarMode == CLAR_MODE_RIT ? "RIT" : "XIT",
                clarOffset < 0 ? "-" : "+",
                abs(clarOffset));
            LCD_SendString(buff);
            return;
        }
    }

    uint32_t tstamp = HAL_GetTick();
    if(force || (tstamp - lastVoltageUpdateTime > 1000)) {
        double voltage = ADC_ReadVoltage(ADC_CHANNEL_2);
        voltage = voltage * 6.7;

        if(force || (abs((int)(voltage*100) - (int)(prevVoltage*100)) >= 15)) {
            // Don't re-render if we are about to transmit
            if(!buttonDitPressed() && !buttonDahPressed()) {
                if(voltage < 9.95) {
                    snprintf(buff, sizeof(buff), "VCC  %.1f", voltage);
                } else {
                    snprintf(buff, sizeof(buff), "VCC %.1f", voltage);
                }

                LCD_Goto(1, 0);
                LCD_SendString(buff);

                prevVoltage = voltage;
                lastVoltageUpdateTime = tstamp;
            }
        }
    }
}

void keyDown() {
    if(!inCWTrainerMode) {
        // CW tone ON
        HAL_GPIO_WritePin(GPIOB, GPIO_PIN_0, GPIO_PIN_SET);
    }

    // enable PWM
    // 512 is half of the Counter Period and means 50% duty cycle.
    __HAL_TIM_SET_COMPARE(&htim3, TIM_CHANNEL_1, 512);
}

void keyUp() {
    if(!inCWTrainerMode) {
        // CW tone OFF
        HAL_GPIO_WritePin(GPIOB, GPIO_PIN_0, GPIO_PIN_RESET);
    }

    // disable PWM
    __HAL_TIM_SET_COMPARE(&htim3, TIM_CHANNEL_1, 0);
}

void switchLPFs(UseLPF_t lpf) {
    HAL_GPIO_WritePin(GPIOB, GPIO_PIN_7, lpf == USE_LPF_40 ? GPIO_PIN_SET : GPIO_PIN_RESET);
    HAL_GPIO_WritePin(GPIOB, GPIO_PIN_6, lpf == USE_LPF_30 ? GPIO_PIN_SET : GPIO_PIN_RESET);
    HAL_GPIO_WritePin(GPIOB, GPIO_PIN_5, lpf == USE_LPF_20 ? GPIO_PIN_SET : GPIO_PIN_RESET);
    HAL_GPIO_WritePin(GPIOB, GPIO_PIN_4, lpf == USE_LPF_17 ? GPIO_PIN_SET : GPIO_PIN_RESET);
}

void changeBand(int32_t delta) {
    currentBand += delta;
    while(currentBand < 0) {
        currentBand += sizeof(bands)/sizeof(bands[0]);
    }
    currentBand %= sizeof(bands)/sizeof(bands[0]);

    switchLPFs(bands[currentBand].lpf);
    changeFrequency(0, false);
    displayFrequency();
}

void enterCWTrainerMode() {
    inCWTrainerMode = true;
}

void leaveCWTrainerMode() {
    inCWTrainerMode = false;
}

void ensureTransmitMode() {
    if(inTransmitMode) {
        return;
    }

    int32_t targetFrequency = bands[currentBand].lastFreq;
    if(clarMode == CLAR_MODE_XIT) {
        targetFrequency += clarOffset;
    }

    SetupCLK(CH_CW, targetFrequency, bands[currentBand].txDriveStrength);

    // NB: turning off VFO produces cleaner TX signal!
    si5351_EnableOutputs(1 << CH_CW);

    enableTx(true);

    LCD_Goto(1, 0);
    LCD_SendString("SWR  ---");

    inTransmitMode = true;
}

void ensureReceiveMode() {
    if(!inTransmitMode) {
        return;
    }
    enableTx(false);

    // Restore the original VFO
    changeFrequency(0, true);
    si5351_EnableOutputs(1 << CH_VFO);
    displayVoltageOrMode(true);
    inTransmitMode = false;
}

ButtonStatus_t buttonPressed(GPIO_TypeDef *GPIOx, uint16_t GPIO_Pin, uint32_t* lastPressed) {
    if(HAL_GPIO_ReadPin(GPIOx, GPIO_Pin) == GPIO_PIN_RESET) {
        uint32_t now = HAL_GetTick();
        if(now - *lastPressed > BUTTON_DEBOUNCE_TIME_MS) {
            *lastPressed = now;
            return BUTTON_STATUS_PRESSED;
        } else {
            return BUTTON_STATUS_DEBOUNCE;
        }
    }
    return BUTTON_STATUS_RELEASED;
}

ButtonStatus_t buttonBandPressed() {
    static uint32_t lastPressed = 0;
    return buttonPressed(GPIOB, GPIO_PIN_14, &lastPressed);
}

ButtonStatus_t buttonFastPressed() {
    static uint32_t lastPressed = 0;
    return buttonPressed(GPIOB, GPIO_PIN_15, &lastPressed);
}

ButtonStatus_t buttonLockPressed() {
    static uint32_t lastPressed = 0;
    return buttonPressed(GPIOA, GPIO_PIN_10, &lastPressed);
}

ButtonStatus_t buttonClarPressed() {
    static uint32_t lastPressed = 0;
    return buttonPressed(GPIOB, GPIO_PIN_1, &lastPressed);
}

ButtonStatus_t buttonKeyerPressed() {
    static uint32_t lastPressed = 0;
    return buttonPressed(GPIOA, GPIO_PIN_7, &lastPressed);
}

// `straightKeyerKeyIsDown` is used to avoid calling keyUp()/keyDown() if we did it already.
// Calling HAL_GPIO_WritePin() too often generates a hearable noise.
bool straightKeyerKeyIsDown;

void initStraightKeyer() {
    straightKeyerKeyIsDown = false;
}

void processStraightKeyerLogic(bool pressed) {
    if(pressed) {
        if(!straightKeyerKeyIsDown) {
            keyDown();
            straightKeyerKeyIsDown = true;
        }
    } else if(straightKeyerKeyIsDown) {
        keyUp();
        straightKeyerKeyIsDown = false;
    }
}

void initIambicKeyer() {
    // iambic keyer doesn't need to init anything
}

void processIambicKeyerLogic(bool ditPressed, bool dahPressed) {
    int32_t now = HAL_GetTick();

    if(isSending && (now >= sendFinish)) {
        keyUp();
        isSending = false;
    }

    if(nextSend == CW_SEND_NONE) {
        if(ditPressed && (lastSent == CW_SEND_DAH)) {
            nextSend = CW_SEND_DIT;
        } else if(dahPressed && (lastSent == CW_SEND_DIT)) {
            nextSend = CW_SEND_DAH;
        } else if(now > keyReadTimeout) {
            if(ditPressed) {
                nextSend = CW_SEND_DIT;
            } else if (dahPressed) {
                nextSend = CW_SEND_DAH;
            }
        }
    }

    if((now > sendTimeout) && (nextSend != CW_SEND_NONE)) {
        if(nextSend == CW_SEND_DIT) {
            sendFinish = now + keyerConfig.ditTimeMs;
            keyReadTimeout = now + keyerConfig.ditTimeMs*2;
        } else if(nextSend == CW_SEND_DAH) {
            sendFinish = now + keyerConfig.ditTimeMs*3;
            keyReadTimeout = now + keyerConfig.ditTimeMs*3;
        }

        lastSent = nextSend;
        nextSend = CW_SEND_NONE;
        sendStart = now;
        sendTimeout = sendFinish + keyerConfig.ditTimeMs;
        isSending = true;
        keyDown();
    }
}

int32_t getDelta(TIM_HandleTypeDef* htim, int32_t *prevCounter, int32_t mult, int32_t div) {
    int32_t currCounter = __HAL_TIM_GET_COUNTER(htim);
    currCounter = mult*(currCounter / div);
    currCounter = 32767 - ((currCounter-1) & 0xFFFF) / 2;
    if(currCounter > 32768/2) {
        // convert ... 32766, 32767, 0, 1, 2 ... into:
        //               ... -2, -1, 0, 1, 2 ...
        // this simplifies `delta` calculation
        currCounter = currCounter-32768;
    }

    if(currCounter != *prevCounter) {
        int32_t delta = *prevCounter-currCounter;
        *prevCounter = currCounter;

        // debounce or skip counter overflow
        if((delta > -10) && (delta < 10)) {
            return delta;
        }
    }

    return 0;
}

void loopKeyer() {
    uint32_t CWTrainerModeEnterTime = 0;
    int32_t prevCounter = 0;
    displayKeyerSettings();
    // read the initial counter value
    (void)getDelta(&htim1, &prevCounter, MULTI_DELTA_MULT, MULTI_DELTA_DIV);

    for(;;) {
        bool ditPressed = buttonDitPressed();
        bool dahPressed = buttonDahPressed();

        if((ditPressed || dahPressed)) {
            CWTrainerModeEnterTime = HAL_GetTick();
            if(!inCWTrainerMode) {
                enterCWTrainerMode();
                if(keyerConfig.straightKey) {
                    initStraightKeyer();
                } else {
                    initIambicKeyer();
                }
            }
        } else {
            uint32_t tstamp = HAL_GetTick();
            if(tstamp - CWTrainerModeEnterTime > keyerConfig.ditTimeMs*8) {
                leaveCWTrainerMode();
            }
        }

        if(inCWTrainerMode) {
            if(keyerConfig.straightKey) {
                processStraightKeyerLogic(ditPressed);
            } else {
                processIambicKeyerLogic(ditPressed, dahPressed);
            }
        }

        int32_t delta = getDelta(&htim1, &prevCounter, MULTI_DELTA_MULT, MULTI_DELTA_DIV);
        if(delta != 0) {
            // reset the keyer logic if dit or dah is presset
            leaveCWTrainerMode();
            keyUp();
            changeKeyerSpeed(delta);
            displayKeyerSettings();
        }

        if(buttonKeyerPressed() == BUTTON_STATUS_PRESSED) {
            break;
        }

        HAL_Delay(5);
    }

    leaveCWTrainerMode();
    saveKeyerConfig();
    displayFrequency();
    displayVoltageOrMode(true);
}
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
int main(void)
{
  /* MCU Configuration--------------------------------------------------------*/

  /* Reset of all peripherals, Initializes the Flash interface and the Systick. */
  HAL_Init();

  /* Configure the system clock */
  SystemClock_Config();

  /* Initialize all configured peripherals */
  MX_GPIO_Init();
  MX_TIM1_Init();
  MX_TIM2_Init();
  MX_ADC1_Init();
  MX_TIM3_Init();
  MX_I2C2_Init();
  /* USER CODE BEGIN 2 */
  init();
  /* USER CODE END 2 */

  /* Infinite loop */
  /* USER CODE BEGIN WHILE */
  while (1)
  {
    loopMain();
    /* USER CODE END WHILE */

    /* USER CODE BEGIN 3 */

  }
  /* USER CODE END 3 */
}

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


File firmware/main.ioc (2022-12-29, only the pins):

Mcu.UserName=STM32F103C8Tx
PA0-WKUP.Signal=ADCx_IN0
PA1.Signal=ADCx_IN1
PA10.Signal=GPIO_Input
PA12.Signal=GPIO_Output
PA13.Signal=SYS_JTMS-SWDIO
PA14.Signal=SYS_JTCK-SWCLK
PA15.Signal=S_TIM2_CH1_ETR
PA2.Signal=ADCx_IN2
PA6.Signal=S_TIM3_CH1
PA7.Signal=GPIO_Input
PA8.Signal=S_TIM1_CH1
PA9.Signal=S_TIM1_CH2
PB0.Signal=GPIO_Output
PB1.Signal=GPIO_Input
PB10.Signal=I2C2_SCL
PB11.Signal=I2C2_SDA
PB12.Signal=GPIO_Input
PB13.Signal=GPIO_Input
PB14.Signal=GPIO_Input
PB15.Signal=GPIO_Input
PB3.Signal=S_TIM2_CH2
PB4.Signal=GPIO_Output
PB5.Signal=GPIO_Output
PB6.Signal=GPIO_Output
PB7.Signal=GPIO_Output
PD0-OSC_IN.Signal=RCC_OSC_IN
PD1-OSC_OUT.Signal=RCC_OSC_OUT

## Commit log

2022-12-03 Move the project from a sandbox repository
    [BOM.csv, active-filter.sch, af-amplifier.sch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]
2022-12-03 Remove DNP components from the BOM
    [BOM.csv]
2022-12-04 Increase the speed of the I2C bus
2022-12-04 Add BN61-202 and 2x 220u capacitors to the BOM
    [BOM.csv]
2022-12-04 BOM: list HFD4/12S as a possible substitute to G6K-2F-Y
    [BOM.csv]
2022-12-04 FW: display the voltage a bit more accurately
2022-12-05 Minor silkscreen + F_Fab layer fixes
    [ayn-dc.kicad_pcb]
2022-12-06 Add a 3D-printable desktop stand model
    [desktop-stand.scad, desktop-stand.stl]
2022-12-07 Add dust-sover.{scad,stl}
    [dust-cover.scad, dust-cover.stl]
2022-12-12 Add a bit more GND vias; update gerber.zip
    [ayn-dc.kicad_pcb]
2022-12-21 FW: continue working even if EEPROM is missing
    [main.c]
2022-12-21 Experiment: move I2C away from 5V bus, use PB10/PB11 (SCL/SDA)
2022-12-21 Fix buttonLockPressed()
2022-12-21 HW: use 5V_DIGITAL and move I2C away from 5V bus
    [ayn-dc.kicad_pcb, ayn-dc.sch]
2022-12-21 HW: minor changes
    [ayn-dc.kicad_pcb]
2022-12-21 ayn-dc-schematic.pdf rev3
2022-12-21 ayn-dc-F_Fab.pdf rev3
    [ayn-dc.kicad_pcb]
2022-12-21 BOM rev3
    [BOM.csv]
2022-12-21 gerber.zip rev3
    [active-filter.sch, af-amplifier.sch, audio-phase-shift.sch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]
2022-12-21 ayn-dc-schematic.pdf rev3, color version
2022-12-21 rev3: minor silkscreen fix
    [ayn-dc.kicad_pcb]
2022-12-28 Update si5351 correction for a new board
    [main.c]
2022-12-29 Use a pull-up resistor @ PA10 (LOCK btn)

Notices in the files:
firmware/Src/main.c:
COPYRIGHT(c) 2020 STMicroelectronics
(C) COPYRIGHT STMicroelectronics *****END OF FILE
